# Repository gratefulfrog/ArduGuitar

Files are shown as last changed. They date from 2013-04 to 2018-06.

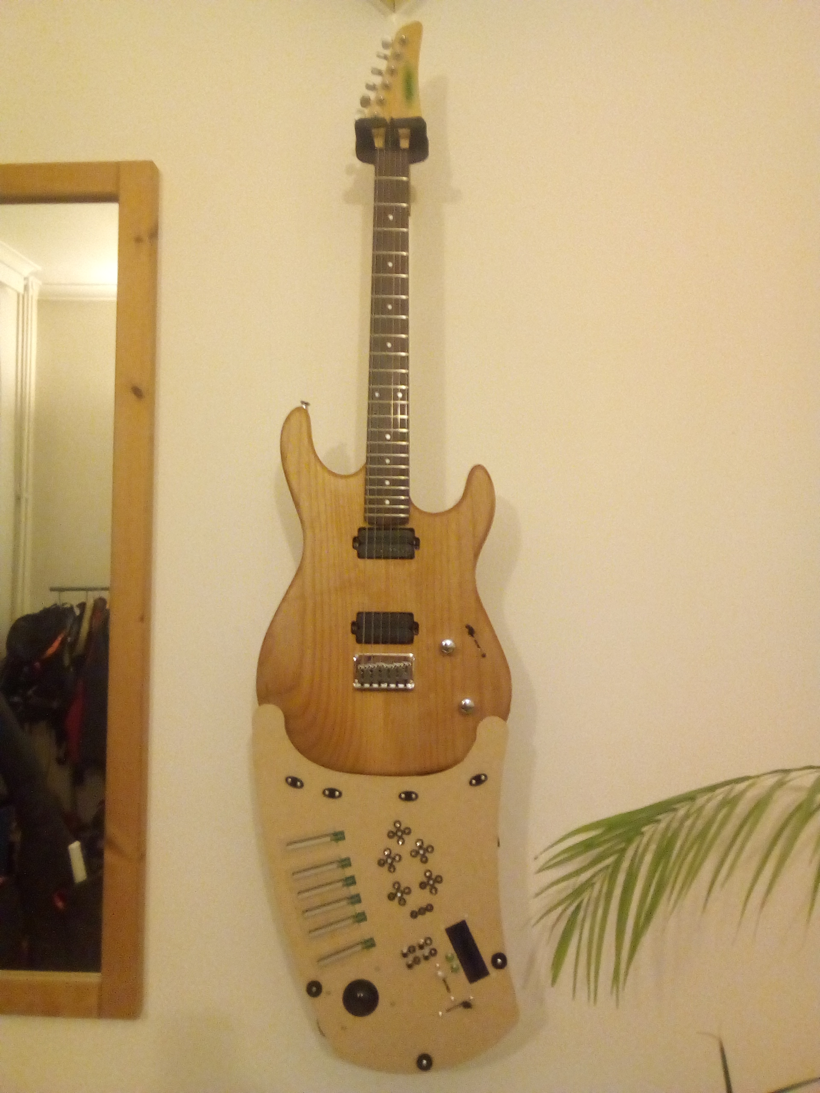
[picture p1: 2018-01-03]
Ardu2/design/POC-3_MAX395/Images/FinalAssembly/IMG_20171226_192559.jpg

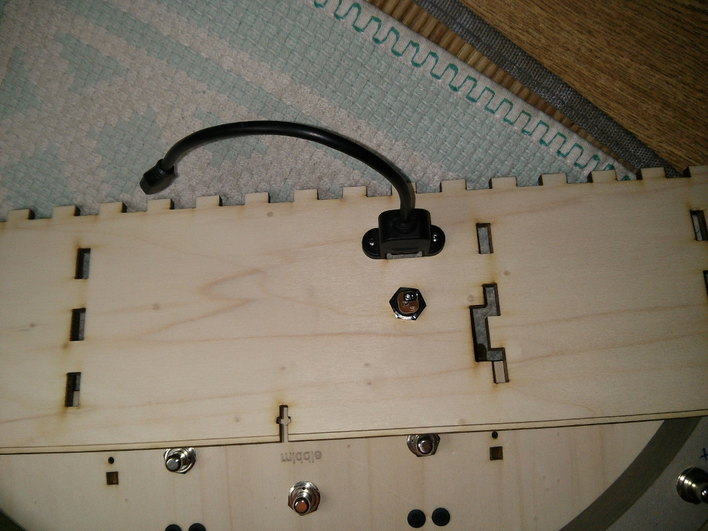
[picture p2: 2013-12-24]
arduino/Layouts/ArduStomp/EnclosureDesign/Photos/IMG_20131224_123505.jpg

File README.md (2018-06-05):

The ArduGuitar 
==========

Following Microsoft's purchase of Github, this project has migrated to gitlab.

*Electric guitars with Pyboards or Arduinos inside* 

by gratefulfrog on www.arduguitar.org

V2 is now nearly ready with a new, super evolved circuit allowing nearly limitless possiblities (2015 06).  

Although, that seemed true at the time (June 2015), it took another year to get to the first workable version of both the hardware and the software!  As of 4 September 2016, we have bench tested v0.99 of the PyGuitar software and will soon put that sw on the hardware and give it a go! 

The new circuit is  driven by a [Micropython Pyboard](http://micropython.org/).

The whole story is documented [here](https://docs.google.com/document/d/1oo2Q_3ezPv_WPeJZZisc5ifhc270i9kwir6oPctKts0/edit?usp=sharing)!

-------------

V1.1 : ArduStomp and ArduGuitar updated functionality

The ArduStomp pedal interface works well and the updated Android GUI does too!

Now ready to move on to Ardu2 !
-------------

V1.0 : a fully functional Android App with Automation capability!

The sound is near perfect, there are no known bugs! 

Now using a heavily shielded Sparkfun BlueSMIRF bluetooth board and micro_protocol_03 at 115200 baud.

-------------

V0.0 : A working Android App controlling an electric guitar!

The Processing code in the android directory works with the Arduino Micro code in the micro_protocol_02 directory to collectively form the first major milestone of the project: A fully functional android app communicating with the Ibanez RG140 circuit. 

The circuit is controled by an arduino "Micro" and communicates via a JY-MCU bluetooth module.  
        
The Processing code is based on the linux python version in the linux directory. The Ketai Processing library is used for android and bluetooth support.
        
There are too many people to thank individually for all the help and support that they gave me during this work, but the core team of Blake, Enrico, Jean and Luis really made this project possible. The Brussels Hackerspace community also provided great ideas to advance the work.

My profound thanks to them and to all the others!

Now using SSH 2016 12 24

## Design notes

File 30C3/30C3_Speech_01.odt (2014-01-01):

# Intro

{SLIDE: opening page}

2 subjects:

1. The ArduGuitar Project
2. Everything that went around the project, the meta-project.

I am not going to define all the terms and references as I speak. giyf.com can do that for you.

I am going to speak for 25 minutes and will take questions at the end. Please hold your questions for the end, or see me later.

I will not be playing the guitar on stage here - there's a limit to how much of a fool I am willing to make of myself.

But, I might make a small demo if there's enough time.

In any case, demos will be given later in the hardware hacking area.

# Who I am

I am characterized by 2 things:

1. Lots of dreams
2. very very little money.

Having very little money, and necessity being the mother of invention, lead me to learn how to get by without buying lots of stuff.

By this I mean scrounging around and fixing broken things.

I think that today there are very few broken things I could not fix, if I really wanted to. I spent all my life learning that.

Along with learning to fix things, I learned to fear breaking things that I would not be able to afford to replace...

Fear is a bad thing.

The song says, “When you've got nothing, you've go nothing to lose.” But it's more like, “when you've got nothing, you can't afford to lose anything!”

So being poor was a mixed blessing:

- it forced me to learn lots of stuff,
- but it made me scared of losing stuff, too.

But there is one other thing that characterizes me:

- Tenacity. I never give up.

This too can be a mixed blessing...

# My Vision

So back to the why I am talking to you.

In my poverty and dream to play electric guitar, over time I had found cheap broken guitars and tried to fix them.

I learned what an electric guitar was made of:

{SLIDE: an electric guitar photo of my Godin}

- pickups which capture the vibration of the string and output an audio signal (whatever that means),
- switches to route the signals from the pickups,
- Volume controls: potentiometers,
- Tone controls: potentiometers + capacitors,
- output jack: where all the signals end up and go off to the amplifier.

So there wasn't much to it.

At this point my understanding of electronics could be completely described by:

{SLIDE: V= IR}

- V = IR

That's all I “knew.” But even that I hardly understood.

This was the state of my being for around 30 years.

In the meantime, I had gotten a job and had revenue that allowed me to do more than dream.

I finally started taking guitar lessons, and got a serious guitar.

The guitar was too serious for me to wreck so I brought it to some luthiers (guitar makers) for adjustment and became friends with them.

From them, I learned that even top-end, ultra-expensive electric guitars were still made exactly as they were in the 1950s.

In fact, some guitars with 5 figure price tags were put together by people who could hardly solder...

I should tell you that for a long time I missed the 1960s.

I'm a hippie since my teenage years....

I thought that the 60s were as good as it could get, and in some ways that remains true today...

But, I love the 21st century. I love what modern technology and Internet have made possible.

I developed a vision of a 21st century electric guitar.

It should maintain the audio qualities of the 20th century guitar, ie. analogue sound from pickups.

But it should be controllable numerically, programmatically, remotely, wirelessly, etc.

Most of all, it should free the guitar of the physical constraints of electromechanical controls (space limitations, human memory, no presets...)

{SLIDE image of the guitar with buttons and the the guitar with a tablet next to it. }

I wondered why guitar electronics had not advanced. I discussed this with many pros in the music business: players, builders, engineers,...

The universal reply comprised 2 points:

{SLIDE : Why not done yet?}

- It would be incredibly difficult and expensive to do anything other than what we have today.
- No one would ever want anything other than what we have today.

Depending on the person, one or the other of those reasons would be underlined.

As the greatest mind of the 20th century said, “What do you care what anybody else thinks?” (if you want to know who said that, giyf.com).

So no one wanting my idea didn't matter. I wasn't trying to sell it anyway.

But the incredible difficulty part was another story. I knew nothing about electronics and had no idea where to begin. I also had plenty of other things to do with my time.

For a year, the project laid dormant.

# Inspiration

{SLIDE: Inspiration: TED: “the community of inspiration”}

One of the things that makes the 21st century a great time to be alive is the rise of communities. Dispersed communities, living on Internet's long tail. (If don't know what the long tail is? giyf.com)

How many people here have heard of Marshall McLuhan? Show your hands please? Can you name any of his books?

Recently, I was re-reading his seminal work “The Medium is the Massage” in the Brussels Metro. Even today, it seems so wildly subversive that I kept looking over my should to see if anyone was watching me...

Luckily, only the NSA was there - aren't they doing a Great Job !?

In 1962 Marshall McLuhan predicted the arrival of Internet:

{SLIDE: Marshall McLuhan}

"In this new age, humankind will move from individualism and fragmentation to a collective identity, the global village."

He was a profoundly forward looking thinker... He also wrote something which was directly applicable to my situation:

"When faced with a totally new situation we tend to always attach ourselves to the objects, to the flavor of the most recent past. We look at the present through a rear-view mirror. We march backwards into the future."

That means that whenever we see something that is new to us, we evaluate it relative to our past, and in particular to our recent past experiences. This can lead people to misunderstand, or to avoid innovation.

An example of this comes from what may be just a made-up conversation but it illustrates the point:

Henry Ford was asked to explain how he knew that people would want his automobiles, did he ask them about what they wanted before he made them?

He replied,

"If I had asked people what they wanted, they would have said faster horses."

Ford wasn't interested in horses.

–

All that thinking was very “a propos” to my project:

- it was too different from anything to which people could refer, so they couldn't imagine it,
- it wasn't a faster horse.

A long time had gone by since I had the idea to make a 21st century electric guitar. I had stopped actively pursuing the problem and was thinking about other things.

Then, at the end of 2012, I went to the Brussels TEDx and that made all the difference.

Mitch Altman spoke at that event and his talk was so inspiring to me that at a break I talked to him about my idea. In a minute he convinced me that it was both a good idea and very possible. He told me to try the Brussels hackerspace community for help.

So all these pros, and people I knew said forget it; I meet some guy I never heard of before who says it will work and I decide to do it.

Is Mitch Altman in the room? If he is, please stand up, Mitch.

{SLIDE: Thanks Mitch!}

Thank you for making all this possible.

# Tech Talk

That was the end of the meta-project talk.

Now, I'm now to talk about the actual implementation of the ArduGuitar and tell you about the what I actually built.

Please excuse me for any errors I may make due to my limited understanding of all this stuff.

So remember the Electric Guitar circuit? A switch, 2 pots and a capacitor.

The real problem was how to make a digitally controlled version of a mechanical analogue potentiometer.

{SLIDE: pot circuit}

Really, that's all that is needed to make a digitally friendly electric guitar. Just replace the old fashioned mechanical potentiometers with something which can add resistance to an analog voltage while being controllable from a digital device.

But, how could that be controlled digitally? I had no idea.

So I asked a question on the Belgian Hackerspace mailing list. At first, it seemed like there was some kind of communication problem.

Ever seen the film, “Cool Hand Luke”? Paul Newman's acting masterpiece?

“What we got here, is a failure to communicate.”

## LED-LDR

But, after a few iterations, and lots of patience on the part of the hackers, someone, in fact a brilliant scientist named Johannes Taelman, suggested using “LED-LDR” to make a digitally controlled variable resistance.

By the way, Johannes is currently in the hardware hacking hall showing off his own really cool project and I strongly recommend visiting him there!

I had no idea what that a LED-LDR was, but I learned that it was actually 2 things:

- a LED to shine light,
- a Light Dependent Resistor that changes its resistance depending on how much light it receives.

Although it took me several weeks to understand enough about what that was and to see how to use it, I soon realized that 2 of these LED-LDRs could be used to make a potentiometer!

{SLIDE: Pot + LED-LDR}

I had gone through Banzi's book “Getting Started with Arduino” so I sort of knew how to control the brightness of a LED …

I was in business.

And I could even use a LED-LDR as an on-off switch, so all the problems were solved!

At this point, someone on the hackerspace mailing list told me,

“It will certainly work to some extent, and even if the result is too noisy or bad quality to be used in music, it will still be huge fun to make it.”

I mention that, because it was a bit worrying. I hadn't considered “noise” at all. My simplistic V = IR understanding didn't contain any notion of noise.

I was going to pay for this later on...

By the way, LED-LDRs come as pre-assembled components. There are several types with slightly differing specs. They are called Vactrols and the best ones come from Perkin-Elmer.

## Secondary Issues

Once the key problem of making a digitally controllable analogue potentiometer was “solved”, sort-of, the rest of the issues in the project needed to be addressed. In particular the overall design.

I read the great book “Making Things Talk” by Tom Igoe and learned about serial communication and Bluetooth. It seemed straightforward.

My conceptual idea was established:

- the guitar would have an arduino embedded in it, with the Vactrols, and a Bluetooth module,
- a bluetooth device, such as an Android phone or tablet, or even a computer would have a GUI to send messages to the Arduino and control the guitar sound.

It seemed simple enough.

And it was!

{SLIDE: schematic}

This is the schematic of what's in the guitar I have here.

- Upper left: pickups, note single and double coil
- Center top: 4 switching Vactrols, LED is just full on or full off, no PWM
- Center: orange raw signal bus, heading to the volume and tone control vactrols
- Center lower: Volume and Tone control Vactrols, Note that a 3rd Vactrol is used in the volume control to shunt and get maximum volume.
- Left lower: blue output bus, with tone capacitor to ground part of the the tone low-pass filter,
- Lower left: output jack to cable to amp; Note the amp ground is the guitar ground; the Arduino & 9V ground is isolated by the opto-isolating Vactrols.
- Right: the Arduino and Bluetooth module and 9V battery.
- lower: the current limiting resistors for the Vactrol LEDs. Note: the R values for the Tone & Volume controls were determined empirically, and seem to be incoherent with the vactrol specs from the Data-sheets... I have no explanation.

Being a pretty good programmer, I got this coded & running quite quickly on a breadboard.

I got an old Ibanez RG-140 and took out all the circuitry.

I connected a very cheap JY-MCU bluetooth module to an Arduino micro which would fit in the guitar's electronics cavity with the vactrols.

I wrote a GUI in Pyside (Python+Qt) for my Linux laptop and everything was cool.

This had taken 2 months. I felt ecstatic!

When I plugged in the Guitar for the first time and it worked... I felt like Dr. Frankenstein when the lightning brought life to his creation!

It was a great moment!

Now, all I had to do was port the python gui to Android!

## Oops...

This is when I began a roller-coast ride, yo-yoing between great hope and total despair for a real really long time.

It turned out to go from Python on linux, to Java on Android was a big step!

I do not know Android, nor the java framework for Android.

I tried to make the Python work on Android, but this was very slow going...

Finally, I discovered that Processing could compile to Android-java!

Cool, I thought, progress at last.

But the GUI components and the Processing Bluetooth library (Ketai) were not easy to get to work - and there were some defects.

I also discovered some errors in Tom Igoe's book - when I wrote to him, through the publisher, he admitted to not testing all his code!!!

But in the end, I had a working Processing GUI running on Android!

{SLIDE: technology}

## More Problems

Suddenly I had a really cool thing and the same professionals who had told me to forget it a year earlier, now loved it and had “suggestions”.

The most obvious suggestion was to “Get rid of that whistling noise!”

Indeed, at each bluetooth exchange, a high frequency clicking or whistling sound came through the amp. I couldn't understand how that was possible since the audio and the control circuits were separated by light!

Another good suggestion was to make it possible to automate the changes of configuration. An example would be to make a tremolo effect by going for high to low volume every ½ second.

Also, in showing it to people and talking with them, I found terminology mismatches: for example, I had called the saved settings “configurations”, but musicians all asked if that was like “presets”.

I changed the name to presets. And made ones that people could relate to like, Eric Clapton's famous “Woman” tone.

The automation was easily done.

Getting rid of the noise was a nightmare.

I asked everyone everywhere for help.

All the forums. I had forum threads with thousands of views...

The Arduino forums were especially friendly, but at the end, no one anywhere seemed to understand what the problem was or how to fix it.

## Finally...

Then I thought to ask Bluetooth experts. After all, maybe the 5€ JY-MCU was just adding noise?

So I contacted Sparkfun support to ask about their Bluetooth modules (costing 30€). They were really nice and tried to help but told me that they used Roving Networks BT chips and advised to contact Roving support.

This was the breakthrough: RN support was great, even though I wasn't a customer! They looked at the spec for the JY-MCU and explained to me what was wrong with it and why their chips cost more: Shielding, respecting standards, more capabilities and DOCUMENTATION!

Getting a new Sparkfun Bluesmirf based on the RN42 bluetooth module got rid of almost all the noise!

Suddenly I had something GREAT!

But still not perfect.

I contacted shielding companies, got samples, learned about how to ground shielding...

## A Small Miracle

Remember I had implemented automation? Well that turned out to be fundamental in searching for the noise source. By running the coms automatically, I discovered that the gold tip of the guitar cable could act like a stethoscope. The other end was plugged into the amp turned up to full volume. I could sniff around the circuit and see where the noise was strongest.

It was not from the Arduino.

It was not from the RN42.

It was from the Serial TX and RX wires connecting the RN42 to the Arduino!

Those square waves were pulsing out EMI !

I heavily shielded the wires from the BT module to the circuit board and life was beautiful!

And I was invited to a Maker Faire...

And there was a write up on HackADay...

And I was invited to speak here today.

Now let's look at it work.

I'm sorry for the latency between the tablet and the computer, the refresh rate is only about 3 frames/sec....

{Screencast & Demo}

# Learn this stuff

Showing your work is really important. Getting feedback, both positive and negative are really helpful.

New ideas come and old problems disappear.

So if you are making stuff, even little stuff, be sure to show it around - and not just to experts.

Show it to anyone who'll take the time to look!

# But now that I had something...

I had something to lose...

I found that I had become afraid to make changes in the code, and in the circuit since I had managed to reach a delicate equilibrium state:

- It worked, but I didn't really know exactly how or why.
- So, if I tweaked something, I might break everything....

I did a lot of code review to improve things.

I am still searching for an electronics person to study the circuit and help me understand the noise and shielding issues...

# The Future: ArduStomp

Big pro-musicians have sound-board operators and stage help etc. These guys manage the effects, and could use the Android version of the ArduGuitar interface to support their guitar players, but what about people like me - remember it was for me!

A foot-pedal would be so much easier than a touch-screen.

Voilà : the ArduStomp!

{sketchup Enclosure 01.skp }

With some problems of its own!

I'll be in the Hardware Hacking Hall this afternoon if anyone wants to see the guitar and Android interface.

# Thank you all for your patience

{SLIDE: thanks}

I'll answer any questions now, or you can see me in the hardware hacking area this afternoon.

# To Show the App set this up before hand!

$ adb devices
List of devices attached
015d8bed2b17f410 device

$ javaws androidscreencast.jnlp

right click to set landscape, then resize window

Sorry for the poor refresh rate.

or (but no better)

$ java -jar droidAtScreen-1.0.2.jar

sketchup Enclosure 01.skp

2013/12/29 www.arduguitar.org @ 30C3 9/9

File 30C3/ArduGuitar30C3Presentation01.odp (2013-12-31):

## www.ArduGuitar.org

Wireless control of an Electric Guitar

## Electric Guitar

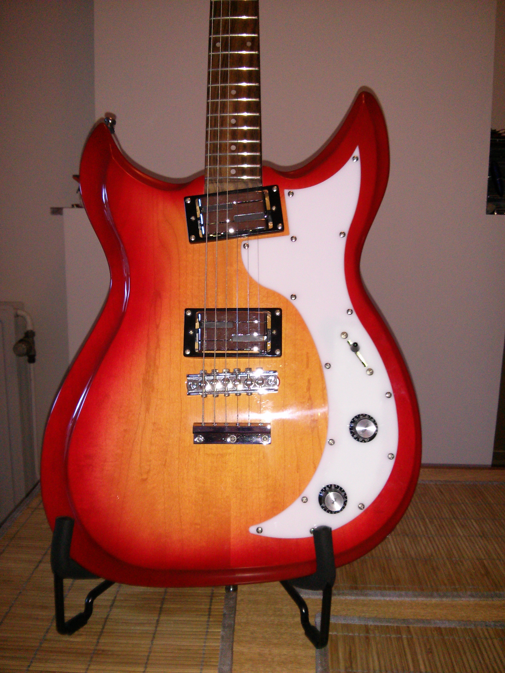
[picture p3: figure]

## All I knew...

  V = IR

## Vision

Control this

Android Phone

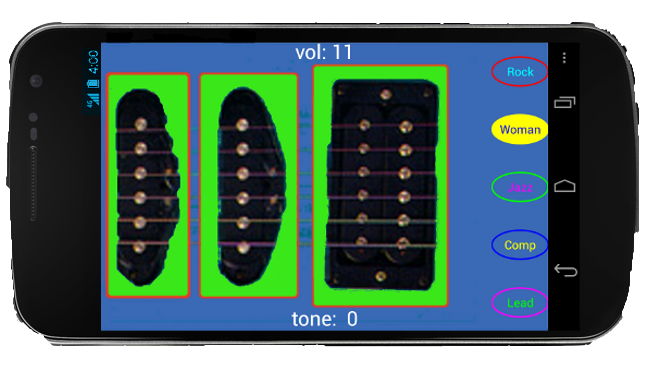
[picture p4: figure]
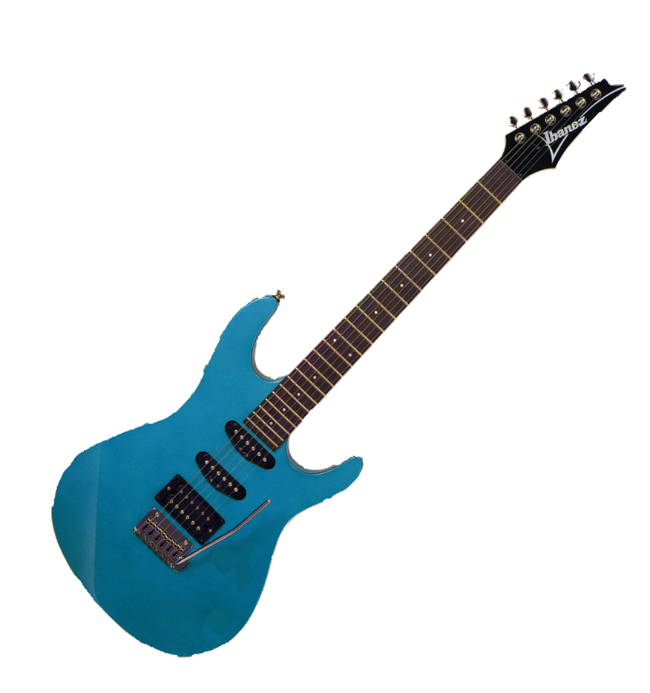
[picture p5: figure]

Play this

Electric Guitar

remote

No Knobs

or Buttons !

## But, why didn't this already exist?

  - Too difficult to build
  - Nobody wants it

## TED

  a Community of Inspiration

## Marshall McLuhan (1962)

  “In this new age, humankind will move from individualism and fragmentation to a collective identity, the global village.”
  and
  "When faced with a totally new situation we tend to always attach ourselves to the objects, to the flavor of the most recent past. We look at the present through a rear-view mirror. We march backwards into the future."

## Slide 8

  Thanks, Mitch!

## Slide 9

the Pot

Potentiometer

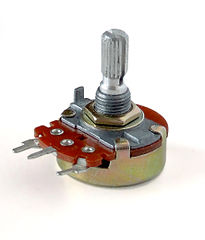
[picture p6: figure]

Manually

turn knob

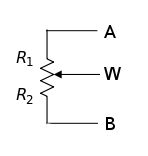
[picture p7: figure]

R1 and R2

Vary

Analog Pot

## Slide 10

the Pot

Potentiometer

Vactrols

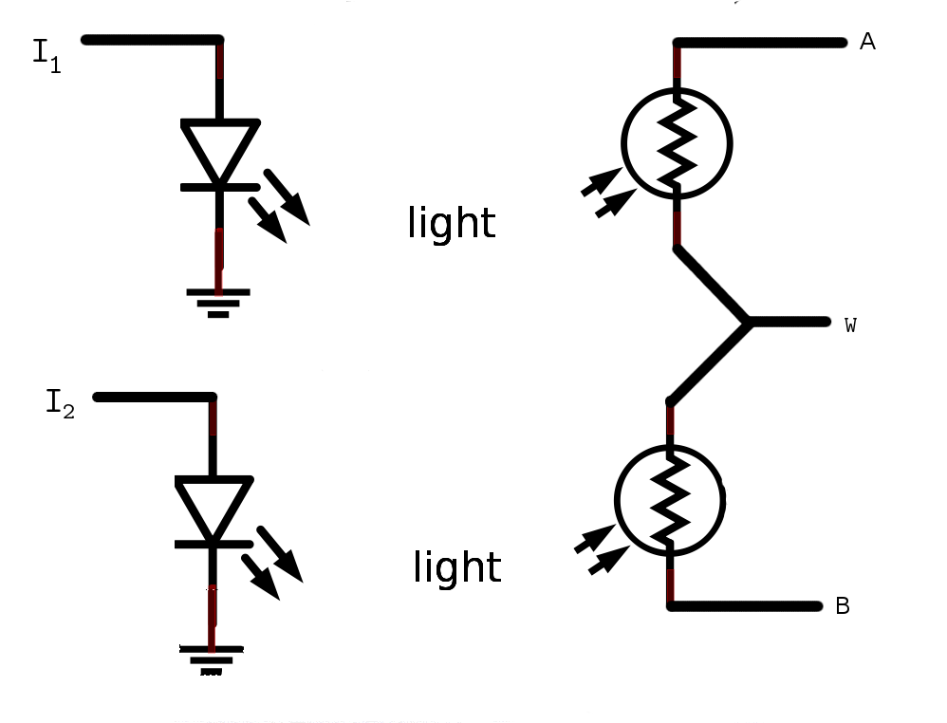
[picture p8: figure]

Manually

turn knob

R1 and R2

Vary

R1

R2

Electronically apply current

R1 and R2

Vary

Digital control - Analog Pot

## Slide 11

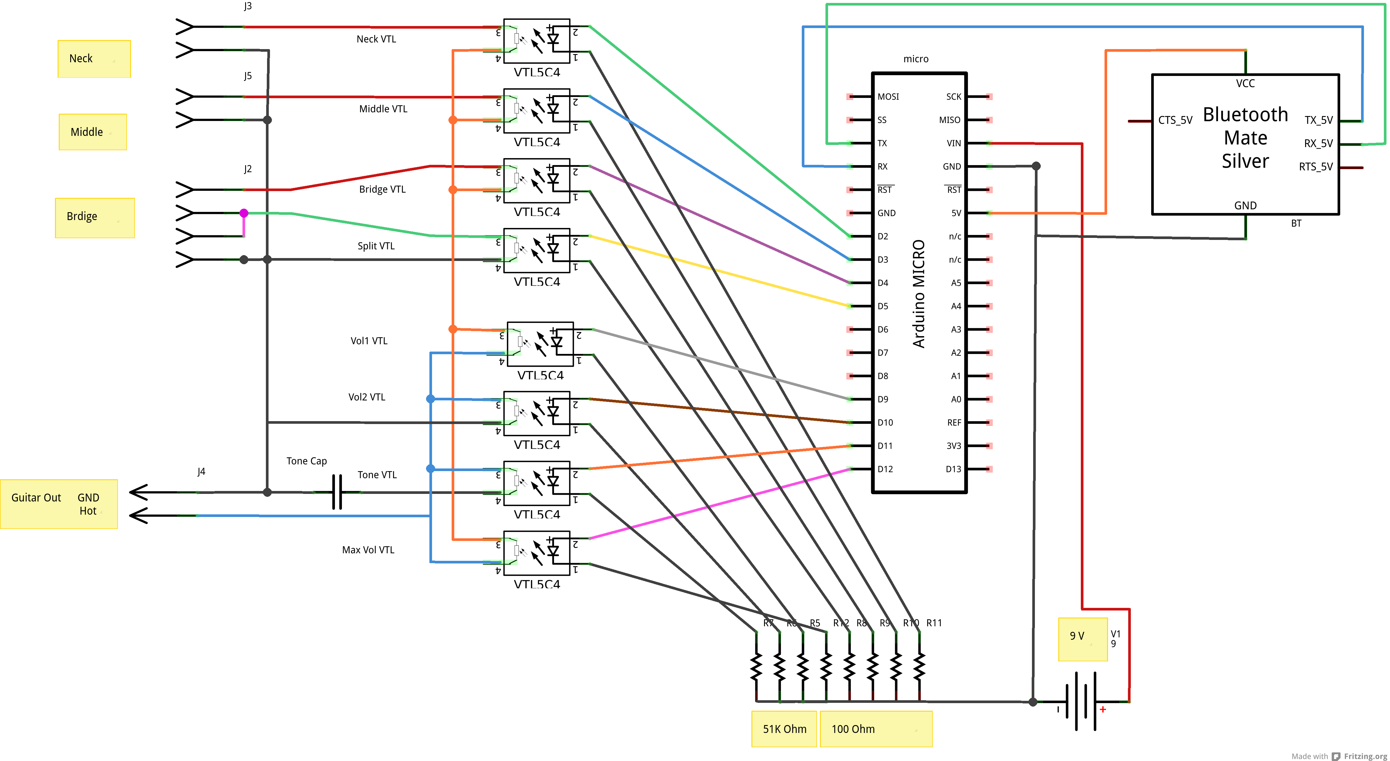
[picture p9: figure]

## ArduGuitar Technology

Vactrols

Arduino Micro C++

Bluetooth

Processing

Android

Bluetooth

wireless

## Thanks!

  www.arduguitar.org

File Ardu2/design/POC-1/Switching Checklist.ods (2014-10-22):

 | OUT+ | OUT- | A+ | A- | B+ | B- | C+ | C- | D+ | D-
A+ | Y | X | X | X | Y | Y | Y | Y | Y | Y
A- | X | Y | X | X | Y | Y | Y | Y | Y | Y
B+ | Y | X | X | X | X | X | Y | Y | Y | Y
B- | X | Y | X | X | X | X | Y | Y | Y | Y
C+ | Y | X | X | X | X | X | X | X | Y | Y
C- | X | Y | X | X | X | X | X | X | Y | Y
D+ | Y | X | X | X | X | X | X | X | X | X
D- | X | Y | X | X | X | X | X | X | X | X
 | OUT+ | OUT- | A+ | A- | B+ | B- | C+ | C- | D+ | D-
A+ | 2D | X | X | X | 2B | 1A | 1B | 1D | 1C | 2A
A- | X | 5D | X | X | 4D | 5A | 4A | 4C | 4B | 5B
B+ | 2C | X | X | X | X | X | 3B | 3D | 3C | 3A
B- | X | 5C | X | X | X | X | 6A | 6D | 6C | 6B
C+ | 7D | X | X | X | X | X | X | X | 7A | 7B
C- | X | 8D | X | X | X | X | X | X | 8A | 8B
D+ | 7C | X | X | X | X | X | X | X | X | X
D- | X | BC | X | X | X | X | X | X | X | X

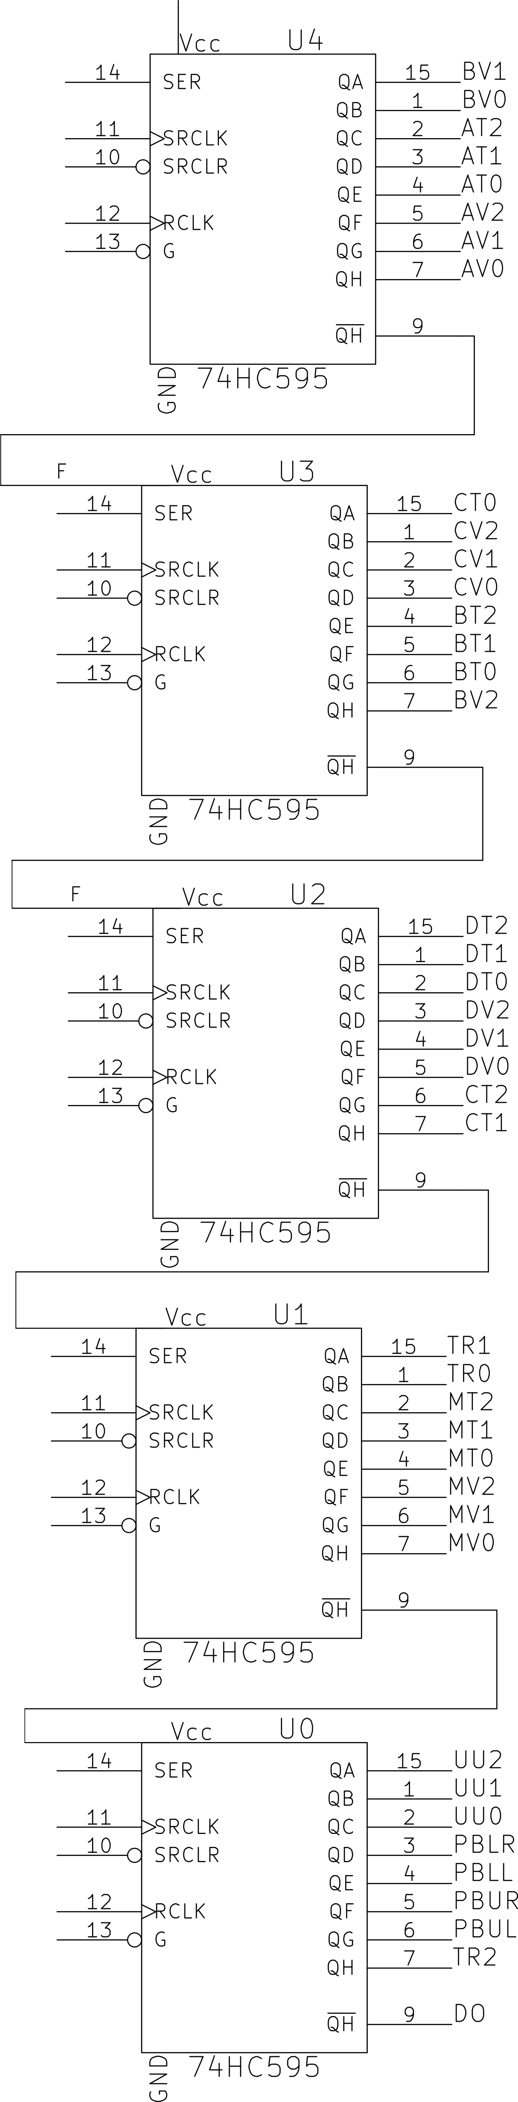
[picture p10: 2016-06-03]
Ardu2/design/POC-3_MAX395/HMI/KicadProjects/Main HMI Circuit/Images/HMI LED PCB Schema.png

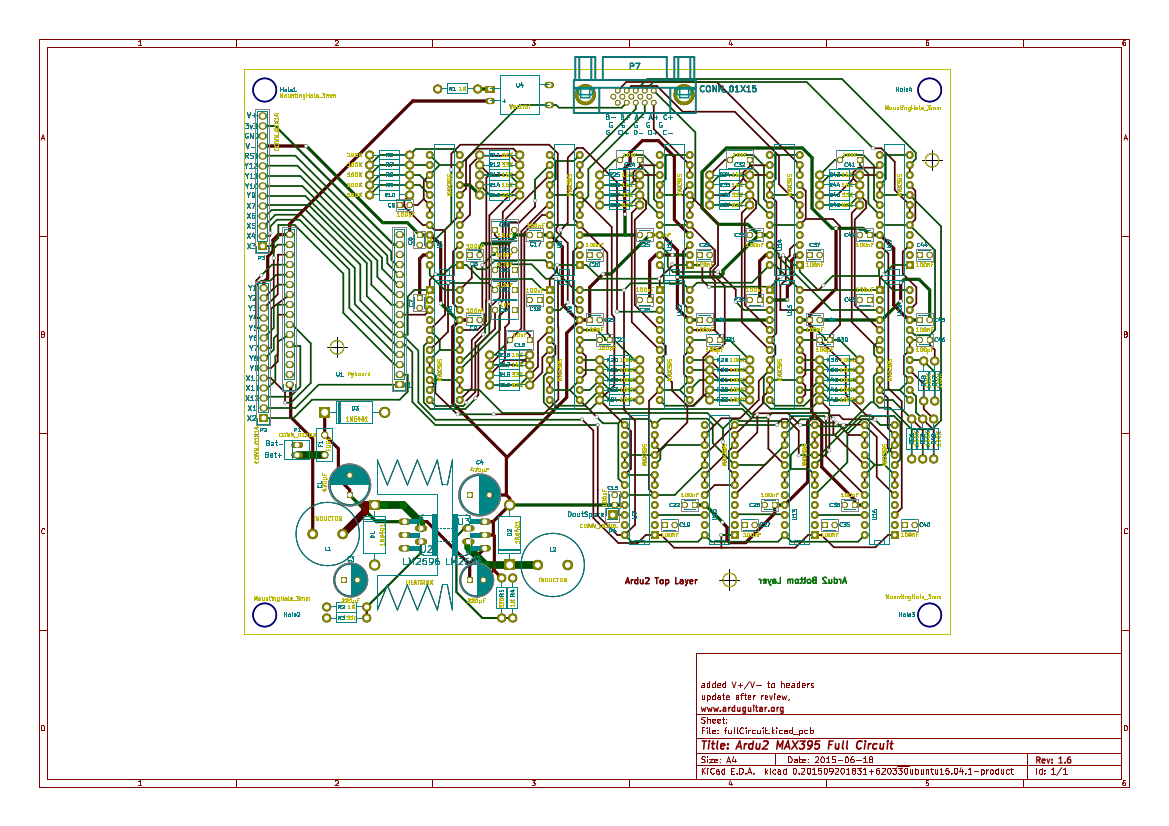
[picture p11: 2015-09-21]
Ardu2/design/POC-3_MAX395/KicadProjects/FullCircuit/Images/V1.8/FullPCBUnfilled.png

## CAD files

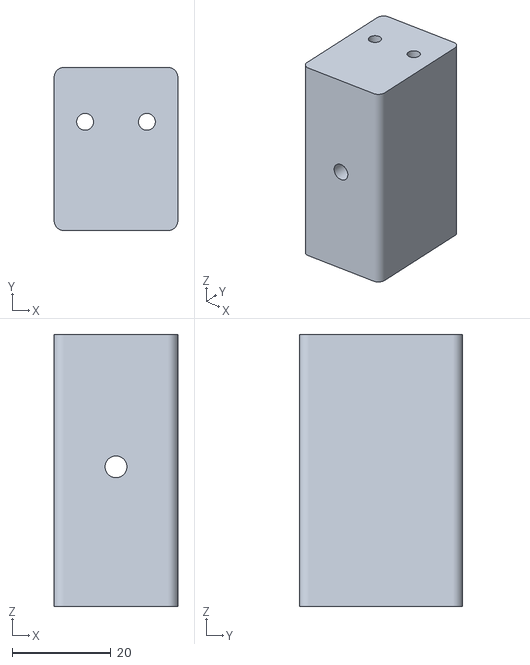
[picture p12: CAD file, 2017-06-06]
Ardu2/design/POC-3_MAX395/HMI/MountingBlocks/lowHoledMountingBlock.stl
25.0 x 33.0 x 55.0

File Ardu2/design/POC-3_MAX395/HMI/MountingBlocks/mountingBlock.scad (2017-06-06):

$fn=100;

// nut dimensions wrench, height, epsilon
/*  UNUSED
wNut = 5.5;
hNut = 2.5;
eNut = 0.2;
*/

// guitar max thickness at butt
hGuitar = 44;

// block height,width,depth
hBlock = 55;
wBlock = 25;
dBlock = 33;


// slot height above base and below top of column, all the rest is computed
sHeight=10;

// dBolt depthwise offset from face away from guitar
dOffset = dBlock/3.;

//hBolt hole offset from base
hOffset = hBlock-hGuitar/2.0; // high hole centered
hlOffset =  28.25;  // low hole average of 28 and 28.5

// bolt diamenters and epsilon
dBolt = 3;
hBolt = 4;
eBolt = 0.2;

// oval cover plate, ratio of ovality 2/1
hPlate = 3;
wPlate = wBlock;
ePlate=1;
ratioPlate = 0.5;

// single hole cylindrical spacer
dCy = 20.0;
hCy = hBlock;

// drilling jig
// 
hPanel = 3.0;
jigEpsilon = 0.2;
wJigCol = 5;
wJigHole = 5 + jigEpsilon;
hJig =  hPlate;
hJigCol = 2*hJig+ hPanel;
wJig = wBlock;
dJig = 50;
dColBack = 23;

module jigCol(wid,h){
    cube([wid,wid,hJigCol], center=true);
}
module jigCols(doCol){
    colY = -dJig+dColBack;
    color("SteelBlue")
    if(doCol){
        translate([-wJig/6,colY,hJigCol/2.])
            jigCol(wJigCol,hJigCol);
    }
    else{
        #translate([wJig/6,colY,0])
            jigCol(wJigHole,hJigCol);
    }
}
module jigPlate(){
    db = dBlock;
    do = dOffset;
    bDia = dBolt;
    bEps = eBolt;
    difference(){  
        union(){
            block(hJig,wJig,dBlock);
            translate([0,(dBlock-dJig)/2.,0])
              block(hJig,wJig,dJig);
        }
        // holes for vertical bolts
        #translate([wBlock/4.0,db/2.0-do,-10])
            column(bEps+bDia/2.0,hBlock+20);
        #translate([-wBlock/4.0,db/2.0-do,-10])
            column(bEps+bDia/2.0,hBlock+20);
    }
}

module jigAll(){
    difference(){
        color("SteelBlue")
        union(){
            jigPlate();
            jigCols(true);
        }
        jigCols(false);
    }
}
                
module cyPlate(){
    color("green")
    //scale([1,1,1])
        cylinder(d=dCy-ePlate,h=hPlate,center=true);
}

module cyBlock(hh,dd){
   color("SteelBlue")
       translate([0,0,hh/2.0])
           cylinder(d=dd, h=hh, center=true);
} 

module plate(){
    color("green")
    scale([1,ratioPlate,1])
        cylinder(d=wPlate-ePlate,h=hPlate,center=true);
}
/* UNUSED
module nut(wrench,thickness){
    // make a nut, centered at 0,0,0
    r = wrench/(2.0*cos(30));
    translate([0,0,-thickness/2.0])
        rotate([0,0,30])
        linear_extrude(height=thickness)
            circle(r,$fn=6);   
}
module slot(w,l,h){
    // make a slot centered at 0,0,0
    translate([0,0,h/2.0])
        cube([w,l,h],center=true);
}
*/
module column(rCol,hCol){
    // make the column, based at 0,0,0
    cylinder(r=rCol,h=hCol);
} 
    
module block(hh,w,d,rr=2,rounded=true){
    // make a block centered at 0,0,0
    color("SteelBlue")
    if (!rounded){
        translate([0,0,hh/2.0]){
            cube([w,d,hh], center=true);
        }
    }
    else{
        x = w/2.-rr;
        y = d/2.-rr;
        hull(){
            translate([-x,-y,0])
                cylinder(r=rr,h=hh);
            translate([-x,y,0])
                cylinder(r=rr,h=hh);
            translate([x,-y,0])
                cylinder(r=rr,h=hh);
            translate([x,y,0])
                cylinder(r=rr,h=hh);
        }
    }
}
        
module all(cHeight,bDia,bEps,low, blocks,plates){
    // make a column of h=cHeight, 
    // with a bolt diamter of bDia, applying bEps
    
    hh =  (low ? hlOffset : hOffset);
    db = dBlock;
    do = dOffset;
    difference(){  
        union(){
            if (blocks)
                block(hBlock,wBlock,db);
            if (plates>0){
                translate([0,db/2.0-do,-5])
                    plate();
            }
            if (plates>1){
                translate([0,db/2.0-do,hBlock+5])
                    plate();
            }
        }
        
        // holes for vertical bolts
        #translate([wBlock/4.0,db/2.0-do,-10])
            column(bEps+bDia/2.0,hBlock+20);
        #translate([-wBlock/4.0,db/2.0-do,-10])
            column(bEps+bDia/2.0,hBlock+20);
        // hole for horizontal bolt
        if (blocks){
            #translate([0,0,hh])
                rotate([90,0,0])
                    translate([0,0,-db/2.-1])
                        column(eBolt+hBolt/2.0,db+2,center=true);
        }
    }
}


module triPlate(hh=3.0,rr=2){
    // make a block centered at 0,0,0
    //color("SteelBlue")
    x = 33/2.0-rr;
    y = 34.0-rr;
    bDia = dBolt;
    bEps = eBolt;
    difference(){
        hull(){
            translate([-x,-y,0])
                cylinder(r=rr,h=hh);
            translate([x,-y,0])
                cylinder(r=rr,h=hh);
            translate([0,0,0])
                cylinder(r=10,h=hh);
        }
        // hole for vertical bolt
        #translate([0,0,-10])
            column(bEps+bDia/2.0,hh+20);
    }
}
module triAll(){
    difference(){
        color("SteelBlue")
        union(){
            triPlate();
            jigCols(true);
        }
        jigCols(false);
    }
}
module cyAll(cHeight,bDia,bEps, cols, plates){
    // make a cylindrical column of h=cHeight, 
    // with a bolt diamter of bDia, applying bEps   
    difference(){        
        union(){
            if (cols){
                cyBlock(cHeight,dCy);
            }
            if (plates>0){
                translate([0,0,-5])
                    cyPlate();
            }
            if (plates>1){
                translate([0,0,cHeight+5])
                    cyPlate();
            }
        }
        // hole for vertical bolt
        #translate([0,0,-10])
            column(bEps+bDia/2.0,cHeight+20);
    }
}

module showThemAll(){
    translate([-wBlock-5,0,0]){   
        all(hBlock,dBolt,eBolt,true,1,2);
        translate([wBlock+5,0,0]){
            all(hBlock,dBolt,eBolt,false,1,2);
            translate([wBlock+5,0,0]){
                cyAll(hCy,dBolt,eBolt,1,2);
            }
        }
    }
}

//showThemAll();
//
module blockAll(low,blocks,plates){
   all(hBlock,dBolt,eBolt,low, blocks, plates);
}


//cyAll(hJig,dBolt,eBolt,1,0);
//blockAll(true,1,0);
//showThemAll();    
//echo("low hole vertical offset", hlOffset);
//echo("high hole vertical offset", hBlock - hOffset);

//jigCols();
//jigPlate();
//jigAll();
triAll();

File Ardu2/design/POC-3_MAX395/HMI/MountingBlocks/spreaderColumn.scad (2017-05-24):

$fn=500;

// nut dimensions wrench, heihht, epsilon
wNut = 5.5;
hNut = 2.5;
eNut=0.2;

// column height, all the rest is computed
hCol =44;

// slot height above base and below top of column, all the rest is computed
sHeight=10;

// bolt diamenter and epsilon
dBolt=3;
eBolt=0.2;

module nut(wrench,thickness){
    // make a nut, centered at 0,0,0
    r = wrench/(2.0*cos(30));
    translate([0,0,-thickness/2.0])
        rotate([0,0,30])
        linear_extrude(height=thickness)
            circle(r,$fn=6);   
}
module slot(w,l,h){
    // make a slot centered at 0,0,0
    translate([0,0,h/2.0])
        cube([w,l,h],center=true);
}

module column(rCol,hCol){
    // make the column, based at 0,0,0
    cylinder(r=rCol,h=hCol);
}

module all(wrench,nHeight,sHeight,cHeight,bDia,nEps,bEps){
    // make a column of h=cHeight, r compute from nut wrench size,
    // with a slot+nut cutaway at sHeight above base, applying nEps
    // with a slot+nut cutaway at sHeight below the top of the column, applying nEps 
    // with a bolt diamter of bDia, applying bEps
    
    wNut=wrench+nEps;
    rNut= wNut/(2.0*cos(30));
    hNut= nHeight/2.0;
    rCyl = 2*rNut;
    difference(){
        column(rCyl,cHeight);
        #translate([0,0,sHeight]){
            nut(wrench,hNut);
            slot(wNut,4*wNut,nHeight+nEps);
        }
        #translate([0,0,cHeight-sHeight]){
            rotate([180,0,0]){
                nut(wrench,hNut);
                slot(wNut,4*wNut,nHeight+nEps);
            }
        }
        #translate([0,0,-1])
            column(bEps+bDia/2.0,cHeight+2);
    }
}


all(wNut,hNut,sHeight,hCol,dBolt,eNut,eBolt);

  

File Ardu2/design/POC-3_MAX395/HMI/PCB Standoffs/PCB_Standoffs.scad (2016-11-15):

// PCB_Standoffs 
// For HMI PCB mounting to back plane

$fn = 100;
lowHeight = 5.0;
highHeight = 9.5;
m3Dia =  3.3;
extDia = 10.0;
rInt = m3Dia/2.0;
rExt = extDia/2.0;
epsilon=1;

module extCyl(height){
    cylinder(r=rExt,h=height, center=false);
}
module intCyl(height){
    translate([0,0,-epsilon/2.0])
        cylinder(r=rInt,h=height+epsilon, center=false);
}
module standoff(hi=false){
    h = hi ? highHeight : lowHeight;
    difference(){
        extCyl(h);
        intCyl(h);
    }
}
standoff(hi=true);

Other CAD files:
arduino/Layouts/ArduStomp/EnclosureDesign/2D/FullDesign08testKerfing.dwg
arduino/Layouts/ArduStomp/EnclosureDesign/2D/FullDesign09/FullDesign09.dwg
arduino/Layouts/ArduStomp/EnclosureDesign/2D/FullDesign10/DWG_2007/FullDesign10_6mm_to_cut12_2007.dwg
arduino/Layouts/ArduStomp/EnclosureDesign/2D/FullDesign10/FullDesign10_3mm_test_Laid_out.dwg
arduino/Layouts/ArduStomp/EnclosureDesign/2D/FullDesign07.dwg
arduino/Layouts/ArduStomp/EnclosureDesign/2D/FullDesign10/DWG_2007/FullDesign10_3mm_to_cut_2007.dwg
arduino/Layouts/ArduStomp/EnclosureDesign/2D/FullDesign08.dwg
arduino/Layouts/ArduStomp/EnclosureDesign/2D/FullDesign10/DWG_2007/FullDesign10_6mm_to_cut_2007.dwg
arduino/Layouts/ArduStomp/EnclosureDesign/2D/FullDesign10/FullDesign10_3mm_text_all_arcs_mirror_14_Laid_out.dwg
arduino/Layouts/ArduStomp/EnclosureDesign/2D/FullDesign06.dwg
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

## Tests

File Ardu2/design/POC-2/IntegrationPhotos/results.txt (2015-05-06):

using 1% pwm at 50000 hz, & 50ohm series resistor, I get 3.5k ohm resistance
over the photo-resistor

using the open_drain, set to high, and 1k resistor, I get 7.7 K ohm resistance 
over the photoresistor, both work well for popless shunting!

g = pyb.Pin('X1',pyb.Pin.OUT_OD)
g.low()
g.high()

c =pwmControl()
shunt(c)
shunt(c,False)

while True:
  pyb.delay(50
  doShunt()
  pyb.delay(50)
  doShunt(False)

Hi,

Here are the results of testing your suggestions :
[quote]
1- If you are able to get good 'popless' shunting at 1% PWM, that tells me that you don't need to drive your Vactrol LED at anything close to the 40-50mA that you will get at 100% duty cycle. You can probably dispense with the BJT and drive the Vactrol directly with the pyboard GPIO pin and the 3.3V supply. IIRC, the GPIO pins can drive or sink up to 20mA. Put your drive pin in open collector mode and use a 200 Ohm resistor in series with the LED to limit the current to about 10mA.[/quote]

I tried this exactly as you said, and it shunts, but the pop is back. I have tried to tune the series resistor, but I am giving up for now and going back to the PWM solution so I can continue testing other parts of the circuit.  I think this will work but the series resistor must be tuned to an appropriate value.  Ideally, it seems that the Vactrol resistance should be 3-5 k ohm to get good quiet shunting.

[quote]2- The Vactrol does not require a common ground between the LED drive circuitry and the audio circuit- you may get better audio performance if you separate them.[/quote]

Definitely not. Without the common ground, the circuit is drowned in noise.

By the way, I actually read some books and understood the idea of shunting and then empirically came to the resistor and PWM values. 

Today, in the lab, we have measured the signal on a scope and saw that on un-shunting the circuit there is a 360 micro-second long spike while the stored  energy in the audio source (an inductive source) attenuates and pure audio is then carried.  So, the vactrol ramp up time is slow enough to allow the energy to dissipate before getting to the amp. (that's what we think, anyway.)

So, the problem is sort of solved and life is as Good as it Gets!

---- The Pop ---

--- The un-shunting Pop ---

With the coil grounded, the current flows to ground at zero volts.

When the coil is un-grounded, the coil tries to conitnue the current flow through the high impedence amp by increasing the voltage. This 360 micro-second long voltage spike is what we hear as a pop.

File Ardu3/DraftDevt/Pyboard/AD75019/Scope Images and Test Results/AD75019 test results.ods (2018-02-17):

 | V to DGND
Pin | 7.6v Analog Supply | 11.3v Analog Supply
5 | <1mv | -1mv to 18mv
6 | <1mv | <1mv
39 | <1mv | <1mv
40 | 4.7v | 4.7v
Resistance between pins
4 Vss | 40 | 4M
41 Vdd | 40 | 7M
42 Vcc | 40 | 100K | Vcc to Pin 40 is far less than the others! and that is where 5v is arriving at the chip!
43 DGND | 40 | 7M
Supply current
Vcc into chip | 0mA
Vdd into chip | 0mA
Chip into Vss | 0mA

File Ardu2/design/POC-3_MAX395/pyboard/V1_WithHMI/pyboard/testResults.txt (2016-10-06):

push: 17152
pop:0x4300
Work:   K:      0b1000011       V:      0x0
PB:     3
Initialized!
Initialized!
Initialized!
Vibrato:        True
setting: None
send reg:       0       10000000
send reg:       1       10110110
send reg:       2       01100001
send reg:       3       00000000
send reg:       4       10000110
send reg:       5       00010000
send reg:       6       10010000
send reg:       7       00010000
send reg:       8       00000000
send reg:       9       10000000
send reg:       10      00001001
send reg:       11      10001001
send reg:       12      00001001
send reg:       13      10000000
send reg:       14      00001001
send reg:       15      10000110
send reg:       16      00001001
send reg:       17      10000010
send reg:       18      00000001
UNshunting
Vibrato Level:  
1
push: 2053
pop:0x805
Work:   K:      0b1000  V:      0x5
push: 17152
pop:0x4300
Work:   K:      0b1000011       V:      0x0
PB:     3
Vibrato:        False
setting: None
Shunting
send reg:       0       10000000
send reg:       1       10110110
send reg:       2       01100001
send reg:       3       00000000
send reg:       4       10000110
send reg:       5       00010000
send reg:       6       10010000
send reg:       7       00010000
send reg:       8       00000000
send reg:       9       10000000
send reg:       10      00001001
send reg:       11      10001001
send reg:       12      00001001
send reg:       13      10000000
send reg:       14      00001001
send reg:       15      10000110
send reg:       16      00001001
send reg:       17      10000010
send reg:       18      00000001
UNshunting
send reg:       18      00000001
UNshunting
push: 4353
pop:0x1101
Work:   K:      0b10001 V:      0x1
push: 4609
pop:0x1201
Work:   K:      0b10010 V:      0x1
push: 4609
pop:0x1201
Work:   K:      0b10010 V:      0x1
push: 4867
pop:0x1303
Work:   K:      0b10011 V:      0x3
VOL:    C       3
((14, 5), (3, 2), (3, 3))
((14, 3), (3, 241))
Reg:    14
Reg:    3
masking: 
['14', '00000011']
masking: 
['3', '11110001']
setting: ((14, 5), (3, 2), (3, 3))
setting: None
Shunting
send reg:       0       10000000
send reg:       1       10110110
send reg:       2       01100001
send reg:       3       00001100
send reg:       4       10000110
send reg:       5       00010000
send reg:       6       10010000
send reg:       7       00010000
send reg:       8       00000000
send reg:       9       10000000
send reg:       10      00001001
send reg:       11      10001001
send reg:       12      00001001
send reg:       13      10000000
send reg:       14      00100001
send reg:       15      10000110
send reg:       16      00001001
send reg:       17      10000010
send reg:       18      00000001
UNshunting

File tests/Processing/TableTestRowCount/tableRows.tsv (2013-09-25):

name | vol | tone | neck | middle | bNorth | bBoth
Rock | 0 | 0 | 0 | 0 | 0 | 0
Woman | 0 | 0 | 0 | 0 | 0 | 0
Jazz | 0 | 0 | 0 | 0 | 0 | 0
Comp | 0 | 0 | 0 | 0 | 0 | 0
Lead | 0 | 0 | 0 | 0 | 0 | 0

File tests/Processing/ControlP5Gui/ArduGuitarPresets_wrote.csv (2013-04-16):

n | v | t | s | l
jazz | 5 | 3 | 0 | 0
rock | 5 | 5 | 4 | 0
mellow | 3 | 3 | 5 | 1

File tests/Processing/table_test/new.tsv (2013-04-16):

x | y | z
1 | 2 | true
3 | 4 | false
123 | 456 | true
123 | 456 | false
123 | 456 | false
123 | 456 | false
123 | 456 | false

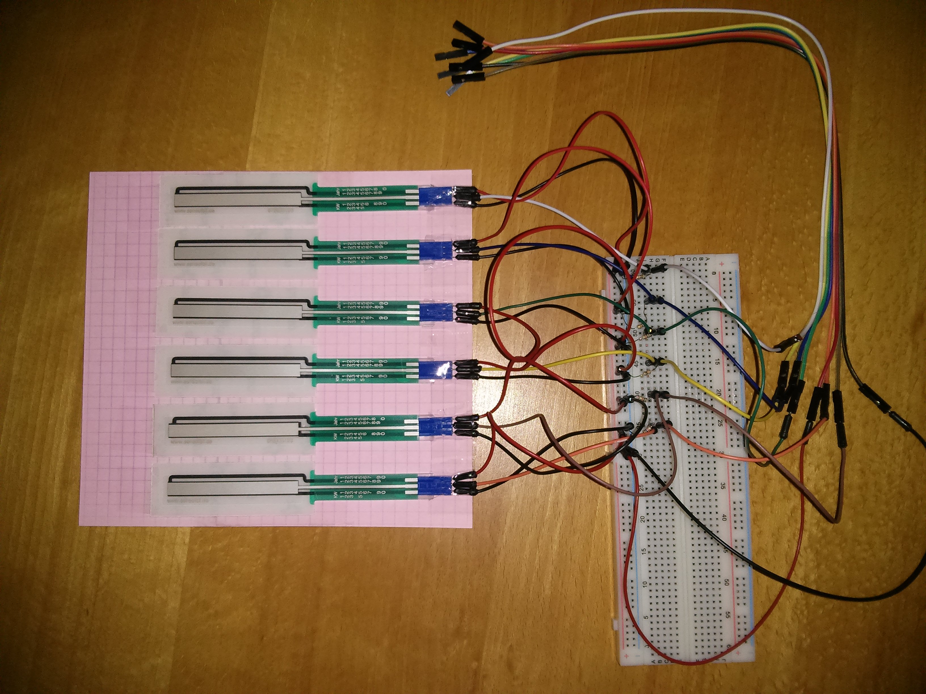
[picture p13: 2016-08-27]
Ardu2/design/POC-3_MAX395/pyboard/images/SplitPot Testbed 2016 08 27.jpg

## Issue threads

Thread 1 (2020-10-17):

Need help for noise from arduino.

kraftZeug, 2020-10-17:
Hey there.
I'm working on electric guitars with onboard midi controlers and i'm amazed at your work.
I wanted to get in touch with you for a practical question: how did you managed the noise from arduino ?

gratefulfrog, 2020-10-17:
Hi KraftZeug,

I should first tell you that all my work has moved to gitlab, so please
look there for code etc.

I had noise on my first circuit, only. I believe that this was due to
several things:

   - lack of a proper PCB: This is in my opinion the main problem. At the
   time, I did not know much and used a proto-board for the components. This
   was a big source of noise. Later, I designed a proper PCB with ground plane
   and fill and the problem was mostly solved.
   - use of unshielded wires for digital data. Another source, but much
   less than the PCB. Use very short shielded wires, soldered !
   - over use of connectors for digital data. Solder your digital cables
   wherever possible.

With these problems fixed, my 2nd circuit and my future 3rd circuit are
noiseless.

Hope this helps!
Cheers,
Bob

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

kraftZeug, 2020-10-17:
Thanks, you helped a lot.
My arduino is wired with dupont connectors and the data wires are not shielded, although guitar wires are. I'll check this..
About the code, I used tttapa's code, Control-Surface.
My next project will be an arduino based analog switching with Red Special (Brian May's guitar) like abilities.
If you're interested, you can find me on facebook and instagram..
Great work anyway, I'll follow to see your next project.

gratefulfrog, 2020-10-17:
No problem, I'm happy to help.

I cannot stress enough the importance of making a proper PCB with proper
ground plane and ground fill. This is really the biggest source of noise.

Good luck with your project!

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

Closed 2020-10-17.

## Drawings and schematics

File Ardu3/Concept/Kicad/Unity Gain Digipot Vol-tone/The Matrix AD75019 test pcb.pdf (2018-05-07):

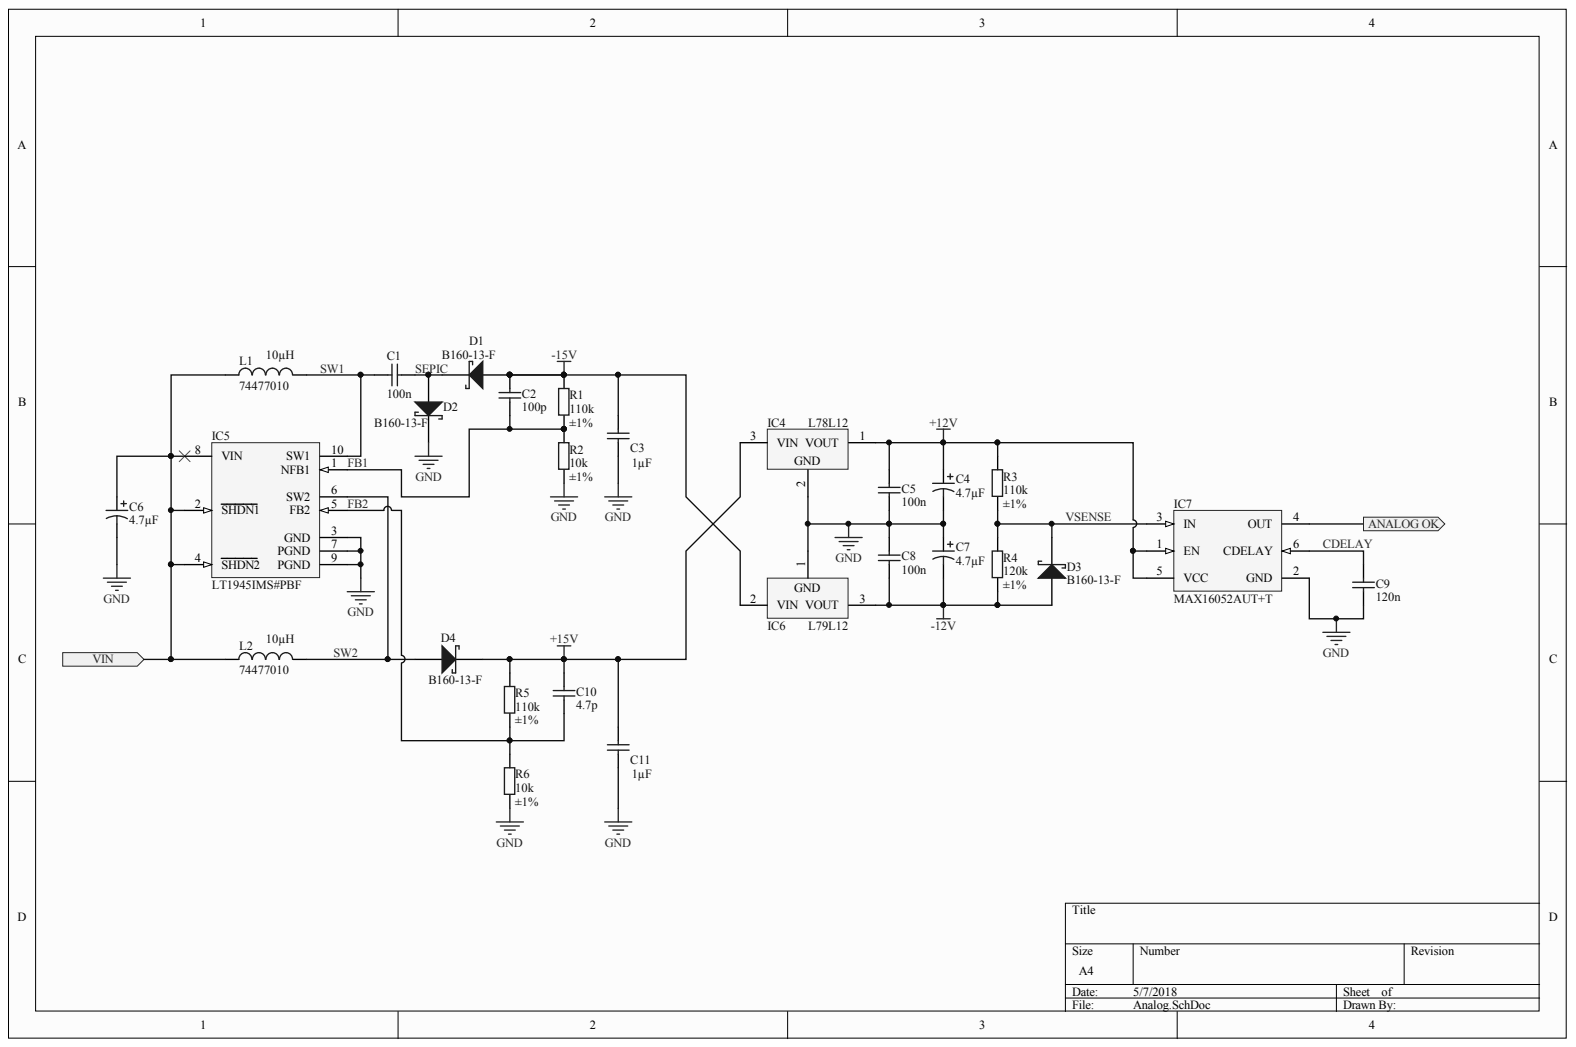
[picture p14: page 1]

1 | 6 C DELA

Numbe r | R evision

: 5/7/2018 | She et of
File : Analog. S chDoc | D r awn By:

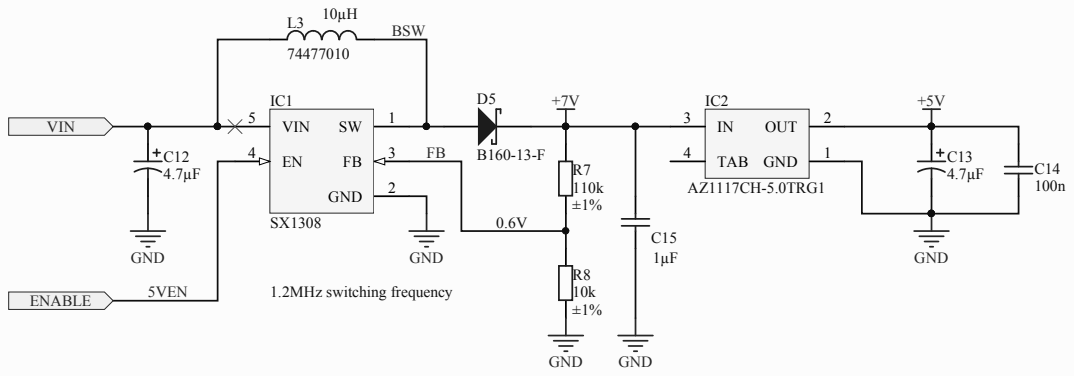
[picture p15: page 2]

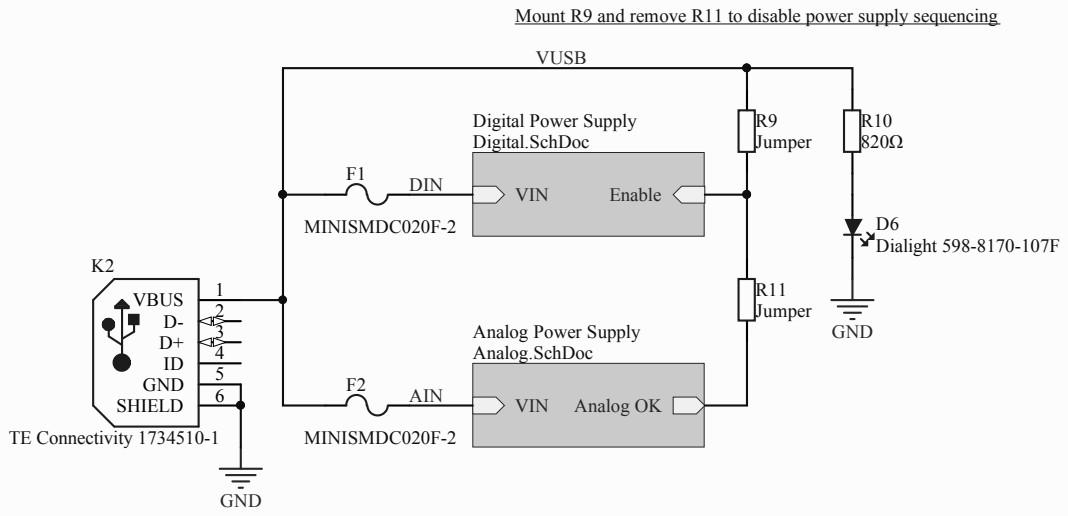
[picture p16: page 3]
R11 Jumpe; R9 Jumpe; E Conne; ight 598-8170-107F; AIN DIN; Mount R9; and re move R11; e pow

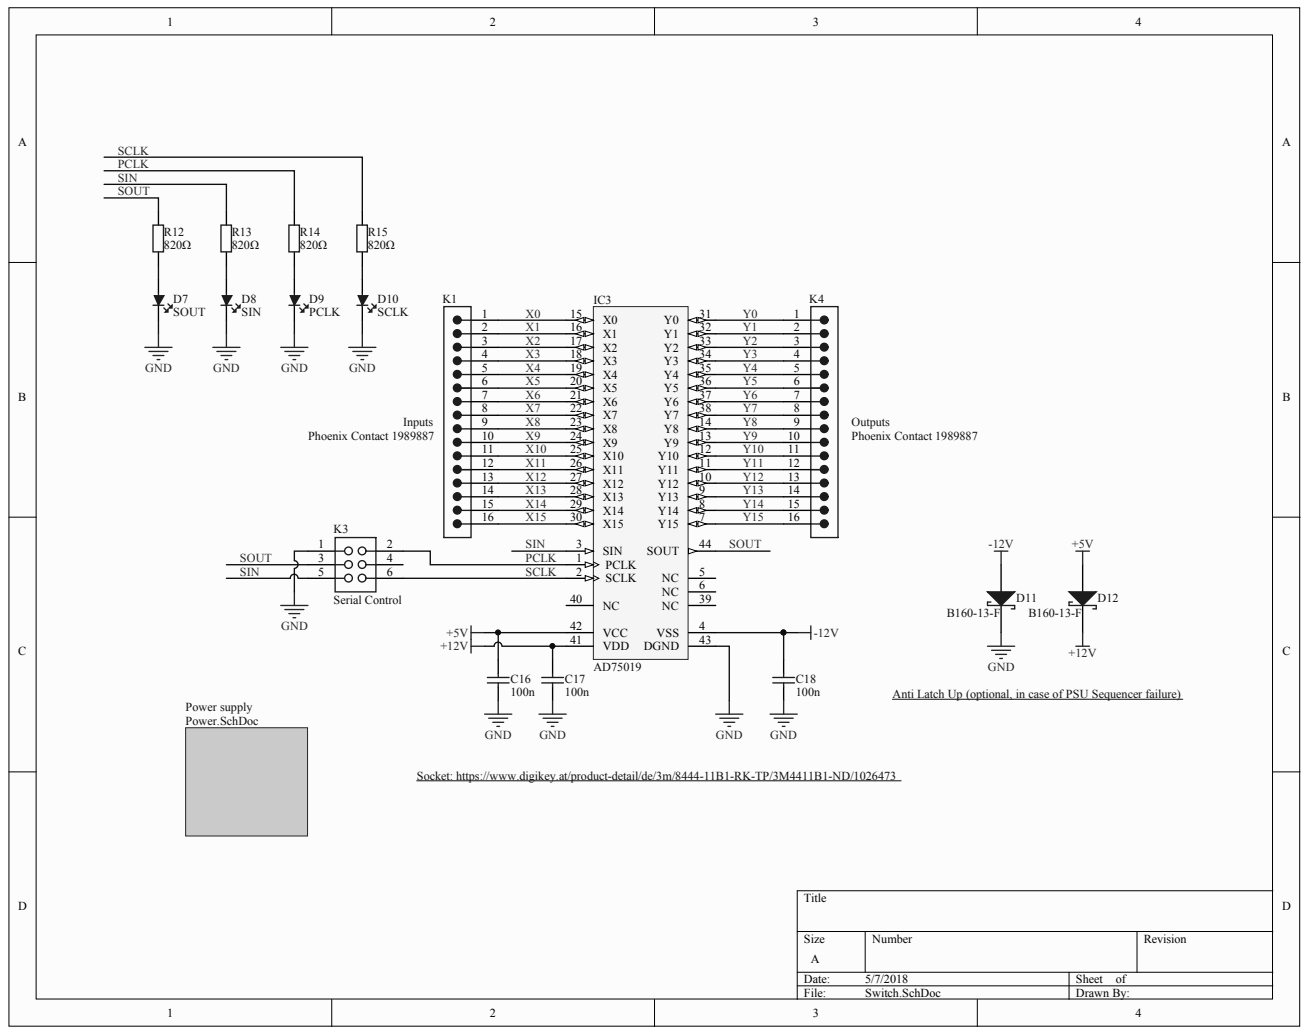
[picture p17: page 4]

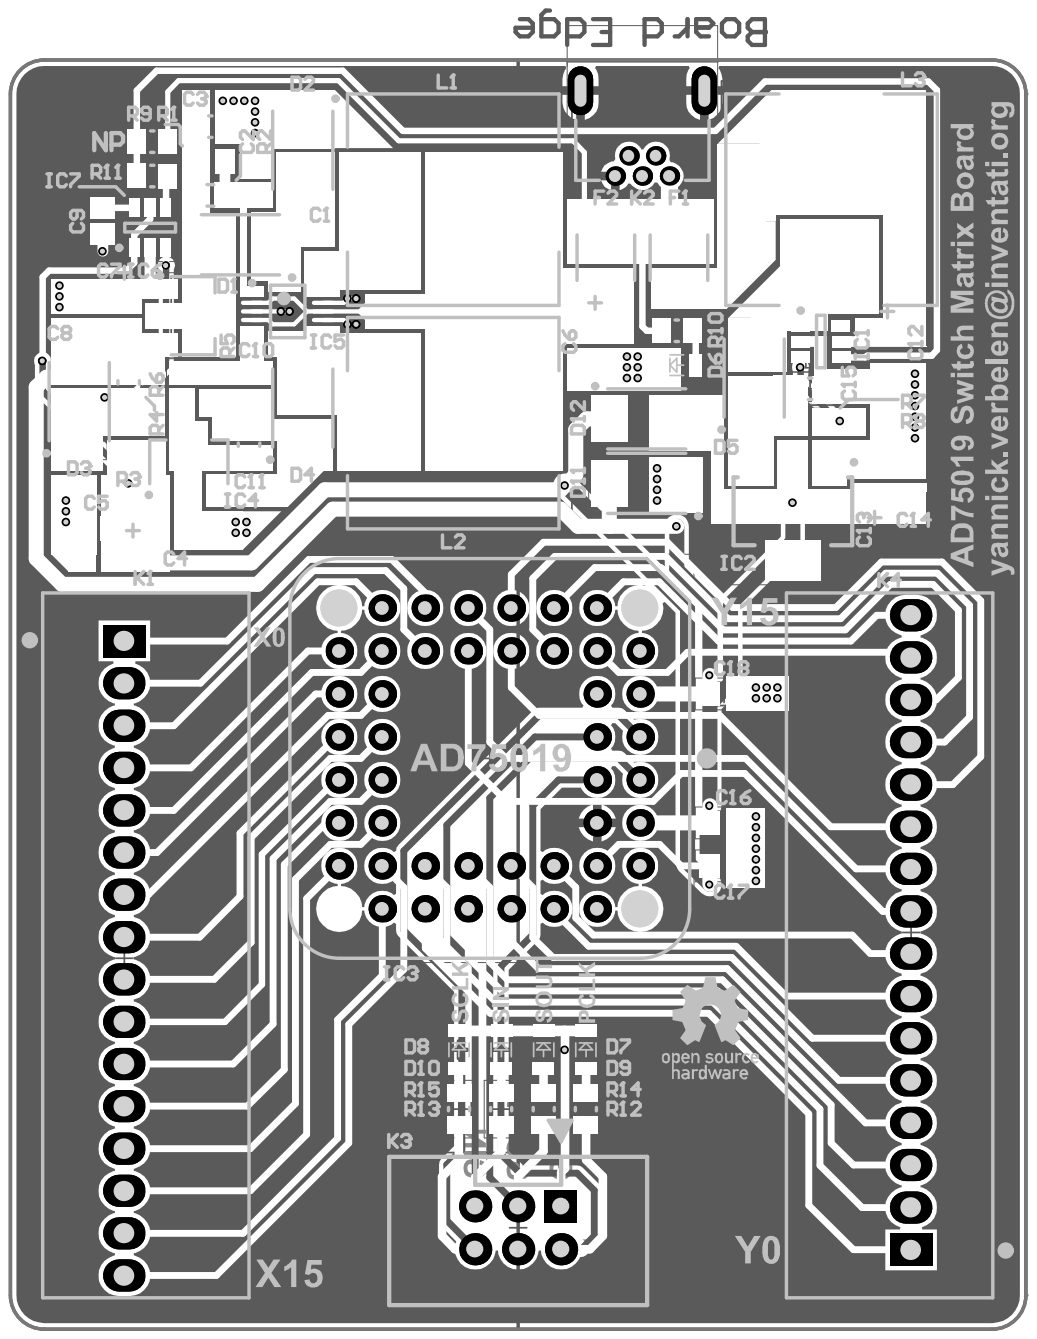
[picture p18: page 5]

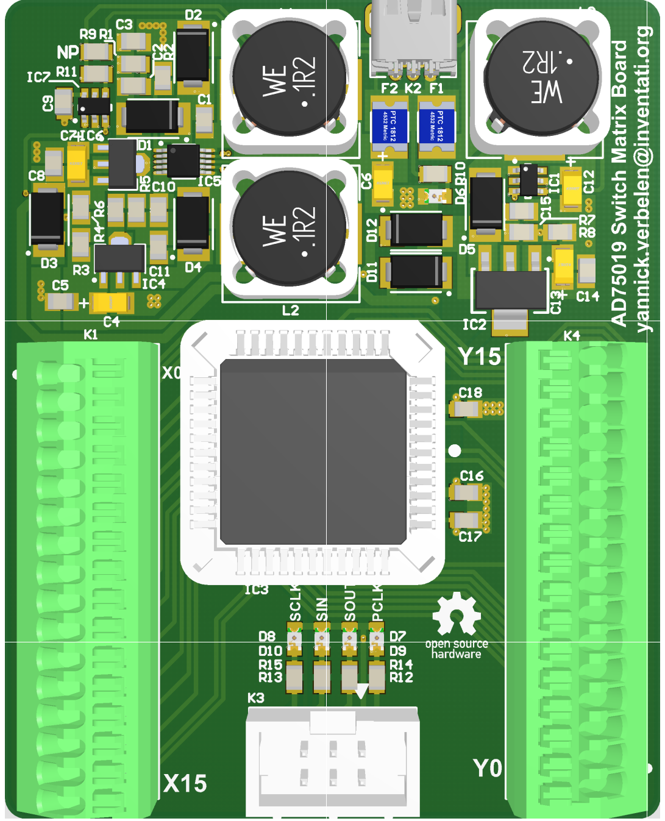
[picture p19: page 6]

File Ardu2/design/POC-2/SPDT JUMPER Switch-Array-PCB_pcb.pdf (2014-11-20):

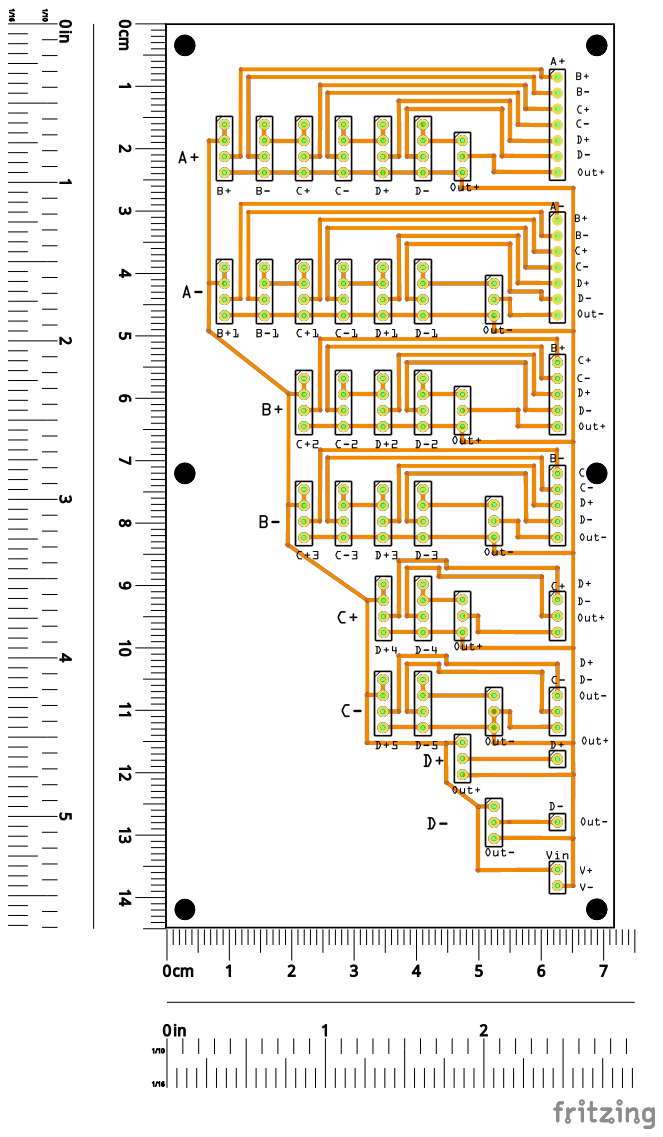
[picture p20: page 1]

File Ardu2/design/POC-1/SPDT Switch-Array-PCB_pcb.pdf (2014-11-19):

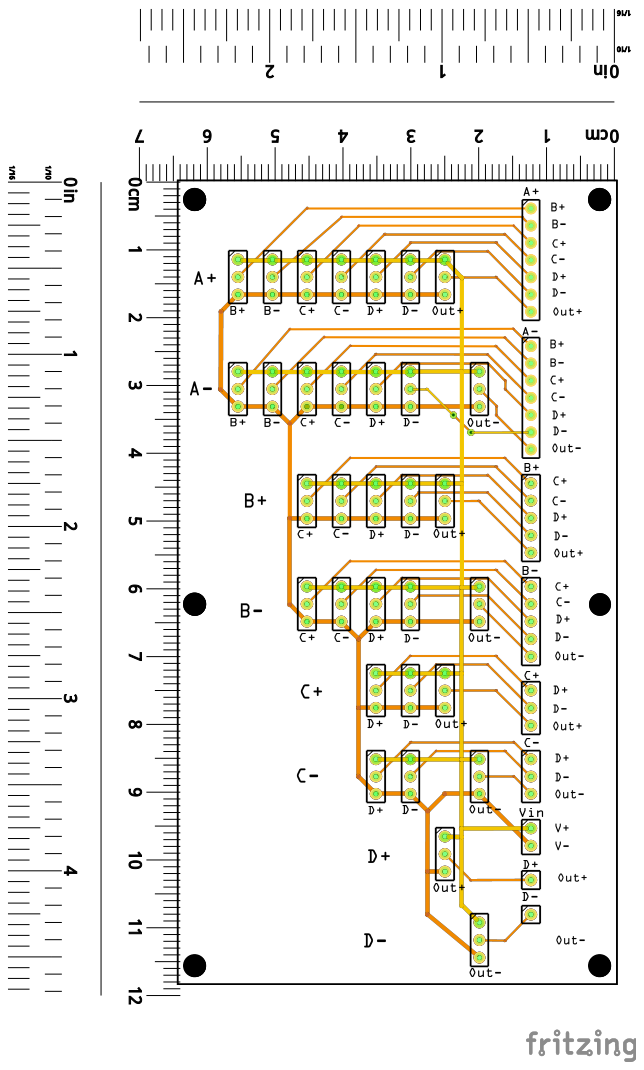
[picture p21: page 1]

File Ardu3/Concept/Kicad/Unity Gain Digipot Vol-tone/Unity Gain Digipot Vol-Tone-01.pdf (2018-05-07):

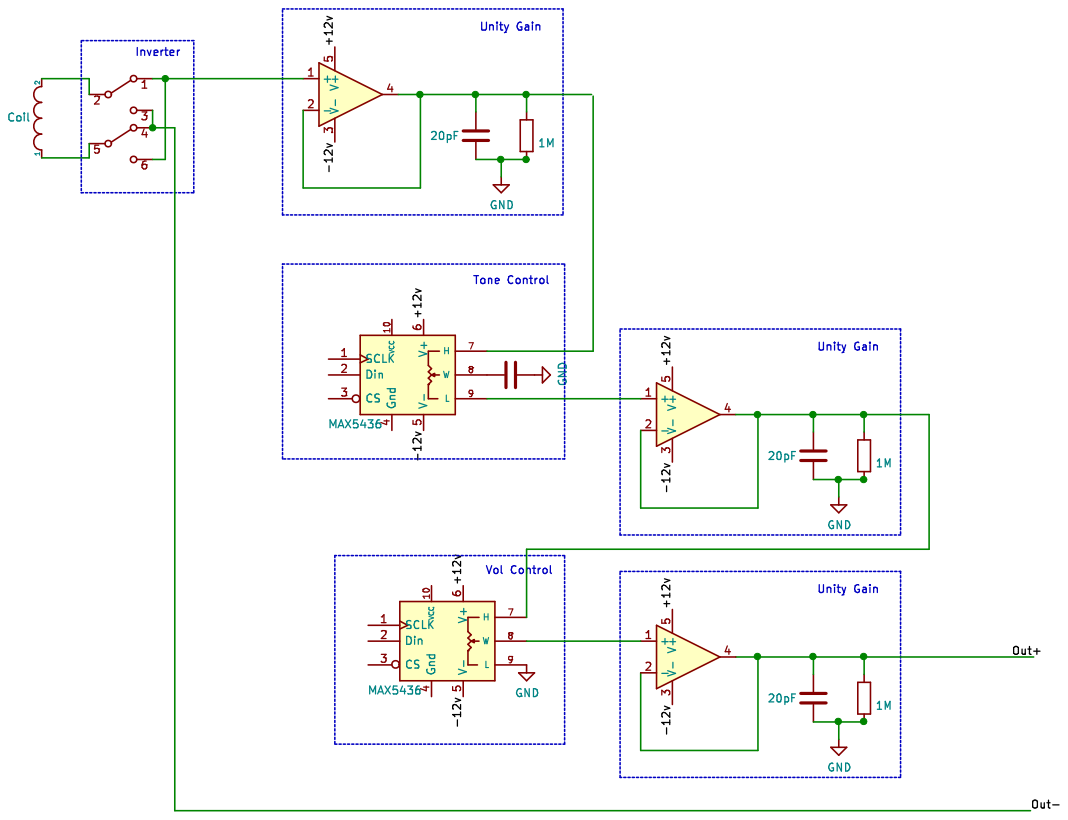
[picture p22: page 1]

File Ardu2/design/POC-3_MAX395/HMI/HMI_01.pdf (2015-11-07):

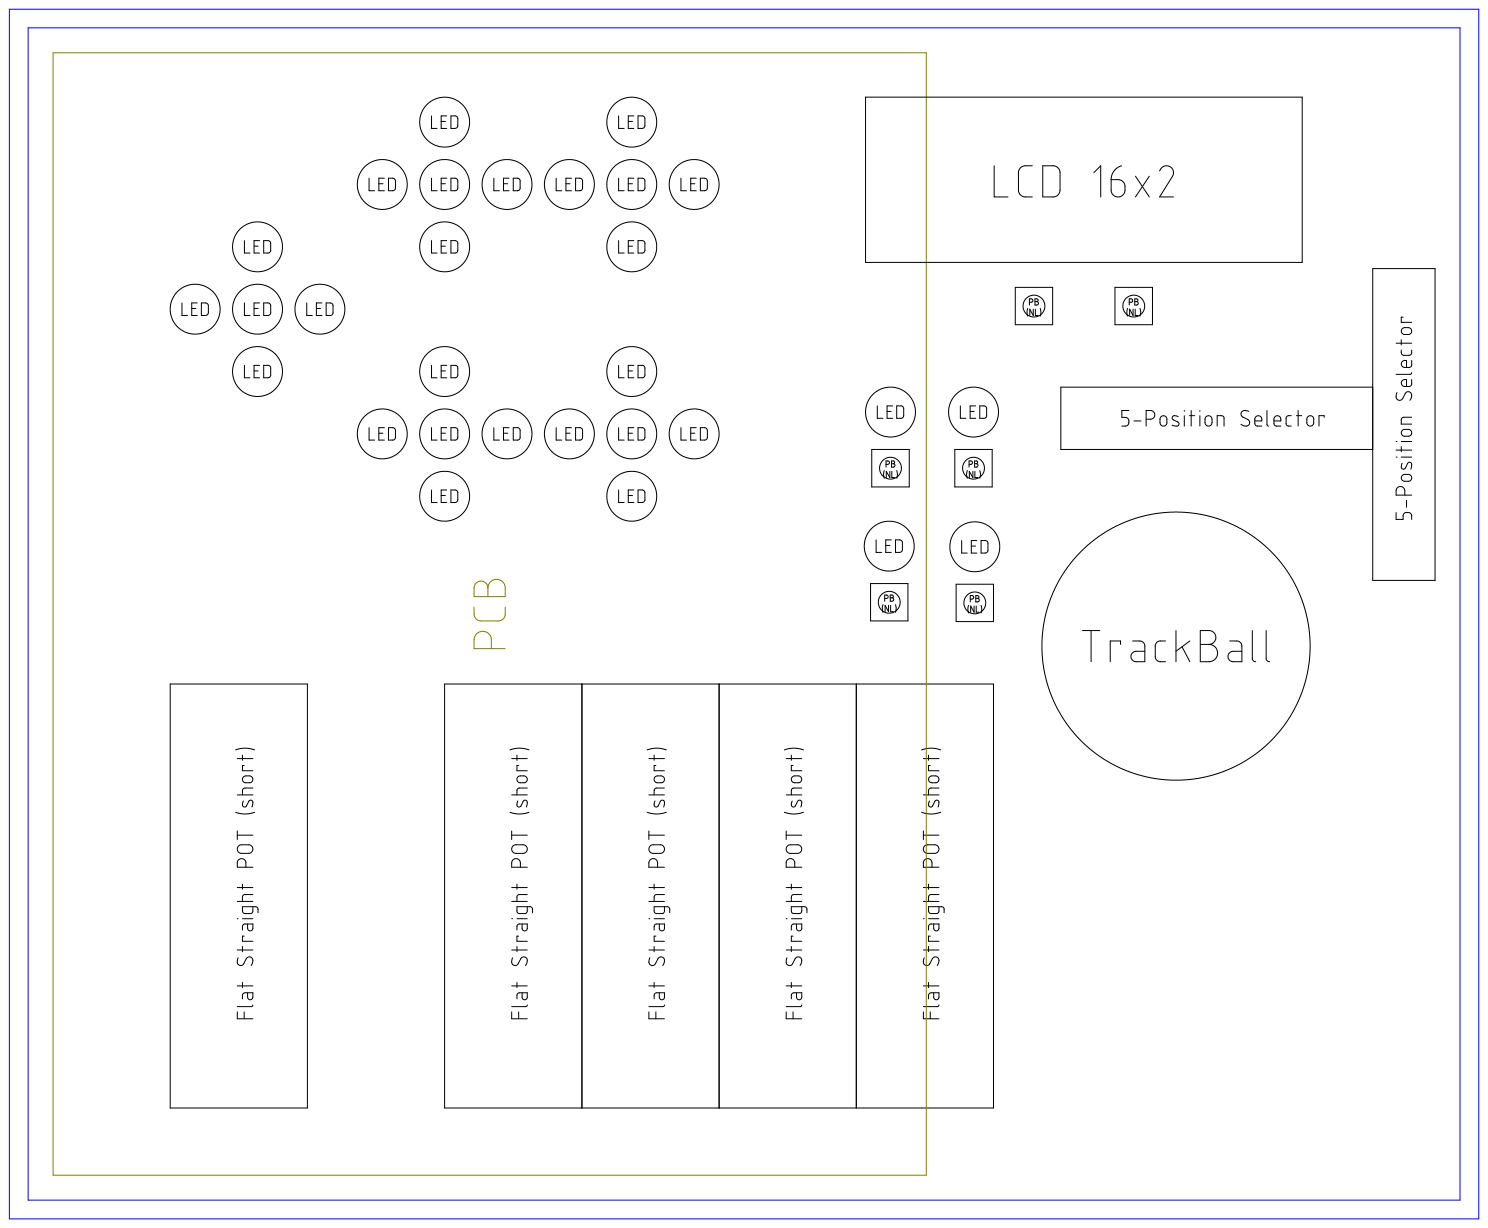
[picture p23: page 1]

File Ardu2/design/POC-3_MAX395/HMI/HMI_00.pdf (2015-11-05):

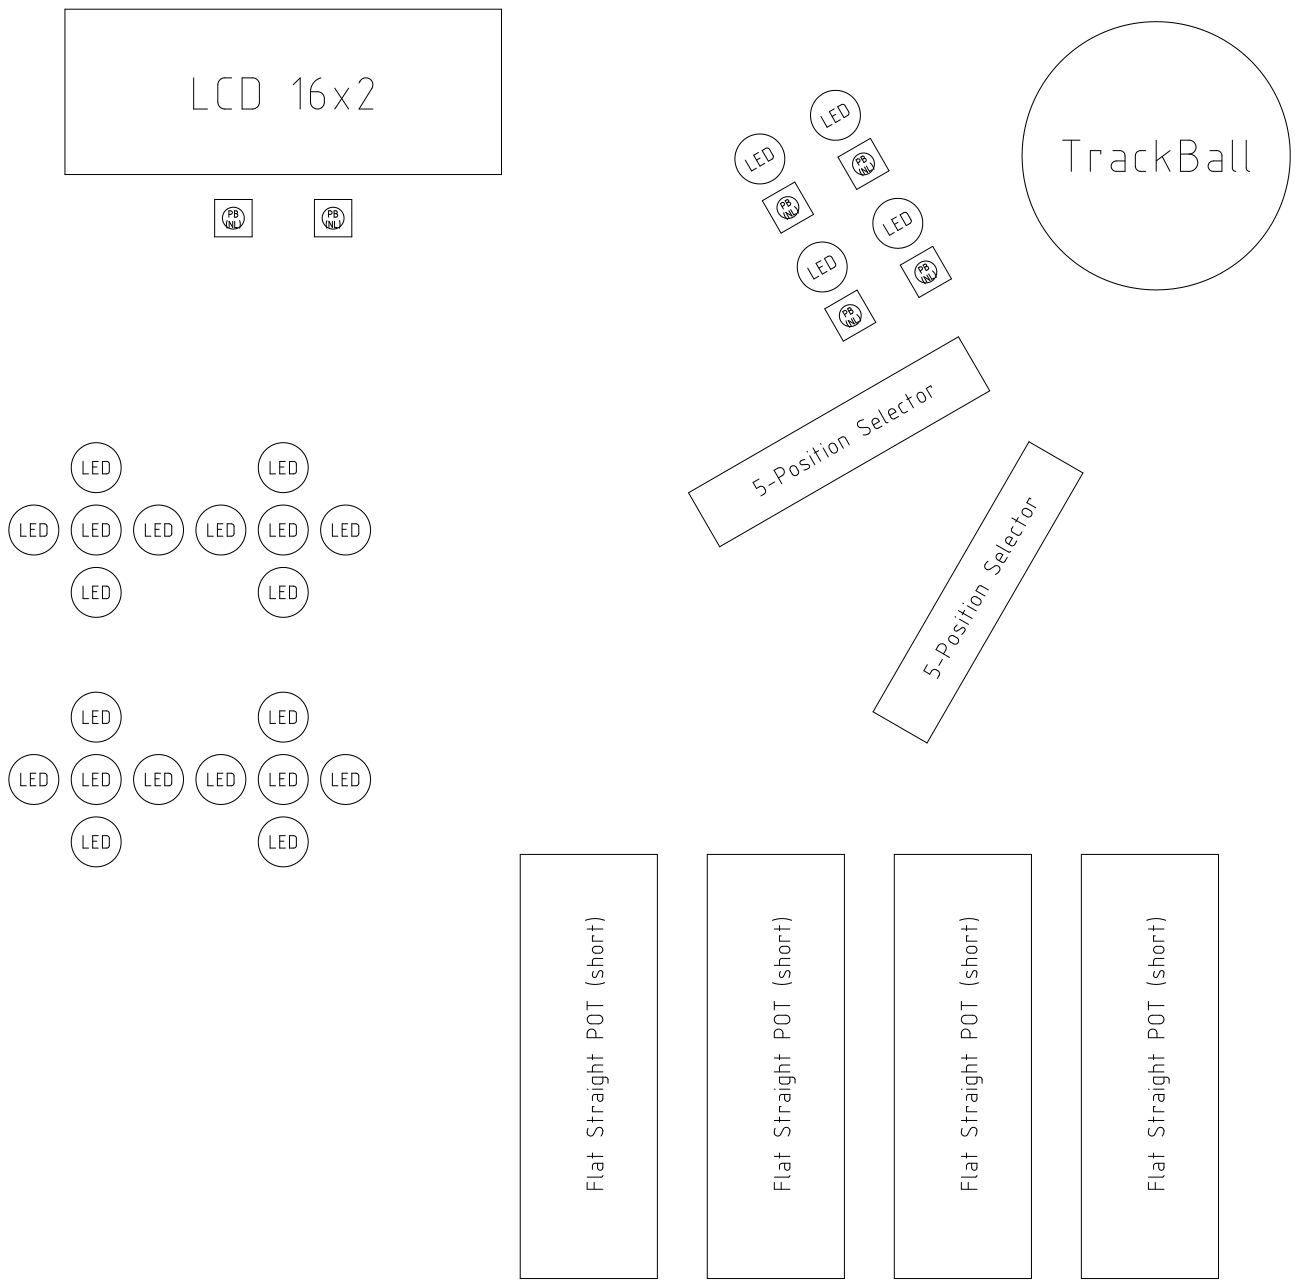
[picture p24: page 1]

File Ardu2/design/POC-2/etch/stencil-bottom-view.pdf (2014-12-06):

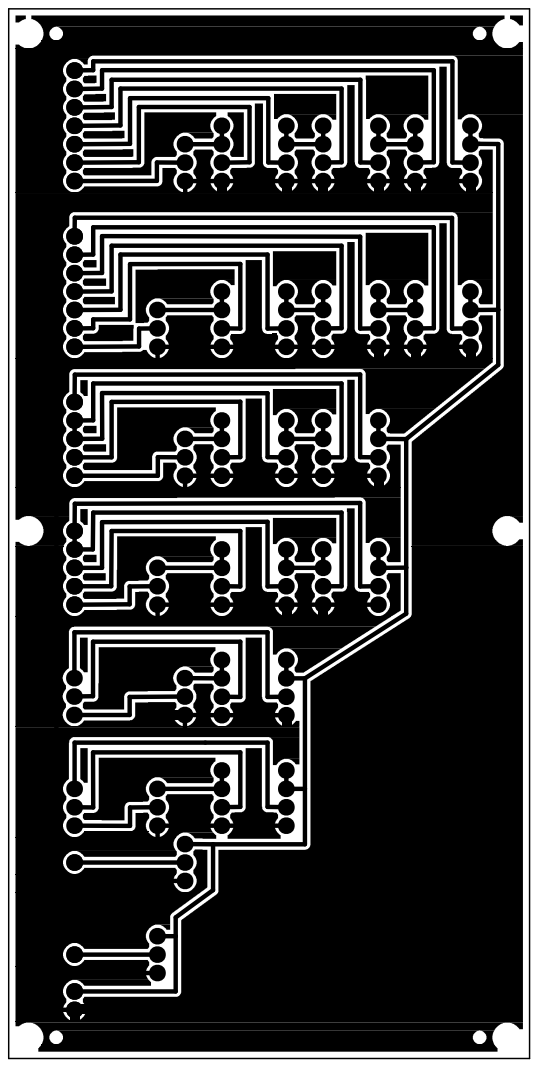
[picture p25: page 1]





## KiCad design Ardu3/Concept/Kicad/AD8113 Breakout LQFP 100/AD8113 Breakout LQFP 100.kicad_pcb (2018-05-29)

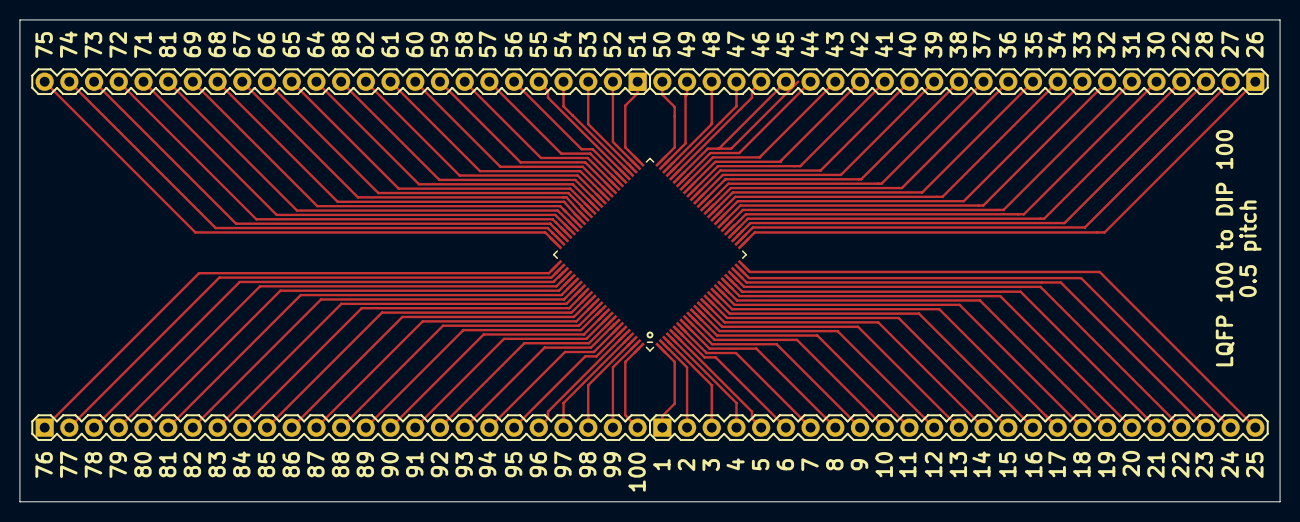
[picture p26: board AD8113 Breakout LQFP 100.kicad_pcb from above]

Board: 2 copper layers, 129.5 x 49.5 mm, 5 parts (0 on the bottom side), 100 nets.

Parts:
J1, J2, J3, J4: Conn_01x25_Male; 1X25
U1: AD8113JST; AD8113JSTZ

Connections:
/P001: J1.1, U1.1
/P002: J1.2, U1.2
/P003: J1.3, U1.3
/P004: J1.4, U1.4
/P005: J1.5, U1.5
/P006: J1.6, U1.6
/P007: J1.7, U1.7
/P008: J1.8, U1.8
/P009: J1.9, U1.9
/P010: J1.10, U1.10
/P011: J1.11, U1.11
/P012: J1.12, U1.12
/P013: J1.13, U1.13
/P014: J1.14, U1.14
/P015: J1.15, U1.15
/P016: J1.16, U1.16
/P017: J1.17, U1.17
/P018: J1.18, U1.18
/P019: J1.19, U1.19
/P020: J1.20, U1.20
/P021: J1.21, U1.21
/P022: J1.22, U1.22
/P023: J1.23, U1.23
/P024: J1.24, U1.24
/P025: J1.25, U1.25
/P026: J2.1, U1.26
/P027: J2.2, U1.27
/P028: J2.3, U1.28
/P029: J2.4, U1.29
/P030: J2.5, U1.30
/P031: J2.6, U1.31
/P032: J2.7, U1.32
/P033: J2.8, U1.33
/P034: J2.9, U1.34
/P035: J2.10, U1.35
/P036: J2.11, U1.36
/P037: J2.12, U1.37
/P038: J2.13, U1.38
/P039: J2.14, U1.39
/P040: J2.15, U1.40
/P041: J2.16, U1.41
/P042: J2.17, U1.42
/P043: J2.18, U1.43
/P044: J2.19, U1.44
/P045: J2.20, U1.45
/P046: J2.21, U1.46
/P047: J2.22, U1.47
/P048: J2.23, U1.48
/P049: J2.24, U1.49
/P050: J2.25, U1.50
/P051: J3.1, U1.51
/P052: J3.2, U1.52
/P053: J3.3, U1.53
/P054: J3.4, U1.54
/P055: J3.5, U1.55
/P056: J3.6, U1.56
/P057: J3.7, U1.57
/P058: J3.8, U1.58
/P059: J3.9, U1.59
/P060: J3.10, U1.60
/P061: J3.11, U1.61
/P062: J3.12, U1.62
/P063: J3.13, U1.63
/P064: J3.14, U1.64
/P065: J3.15, U1.65
/P066: J3.16, U1.66
/P067: J3.17, U1.67
/P068: J3.18, U1.68
/P069: J3.19, U1.69
/P070: J3.20, U1.70
/P071: J3.21, U1.71
/P072: J3.22, U1.72
/P073: J3.23, U1.73
/P074: J3.24, U1.74
/P075: J3.25, U1.75
/P076: J4.1, U1.76
/P077: J4.2, U1.77
/P078: J4.3, U1.78
/P079: J4.4, U1.79
/P080: J4.5, U1.80
/P081: J4.6, U1.81
/P082: J4.7, U1.82
/P083: J4.8, U1.83
/P084: J4.9, U1.84
/P085: J4.10, U1.85
/P086: J4.11, U1.86
/P087: J4.12, U1.87
/P088: J4.13, U1.88
/P089: J4.14, U1.89
/P090: J4.15, U1.90
/P091: J4.16, U1.91
/P092: J4.17, U1.92
/P093: J4.18, U1.93
/P094: J4.19, U1.94
/P095: J4.20, U1.95
/P096: J4.21, U1.96
/P097: J4.22, U1.97
/P098: J4.23, U1.98
/P099: J4.24, U1.99
/P100: J4.25, U1.100

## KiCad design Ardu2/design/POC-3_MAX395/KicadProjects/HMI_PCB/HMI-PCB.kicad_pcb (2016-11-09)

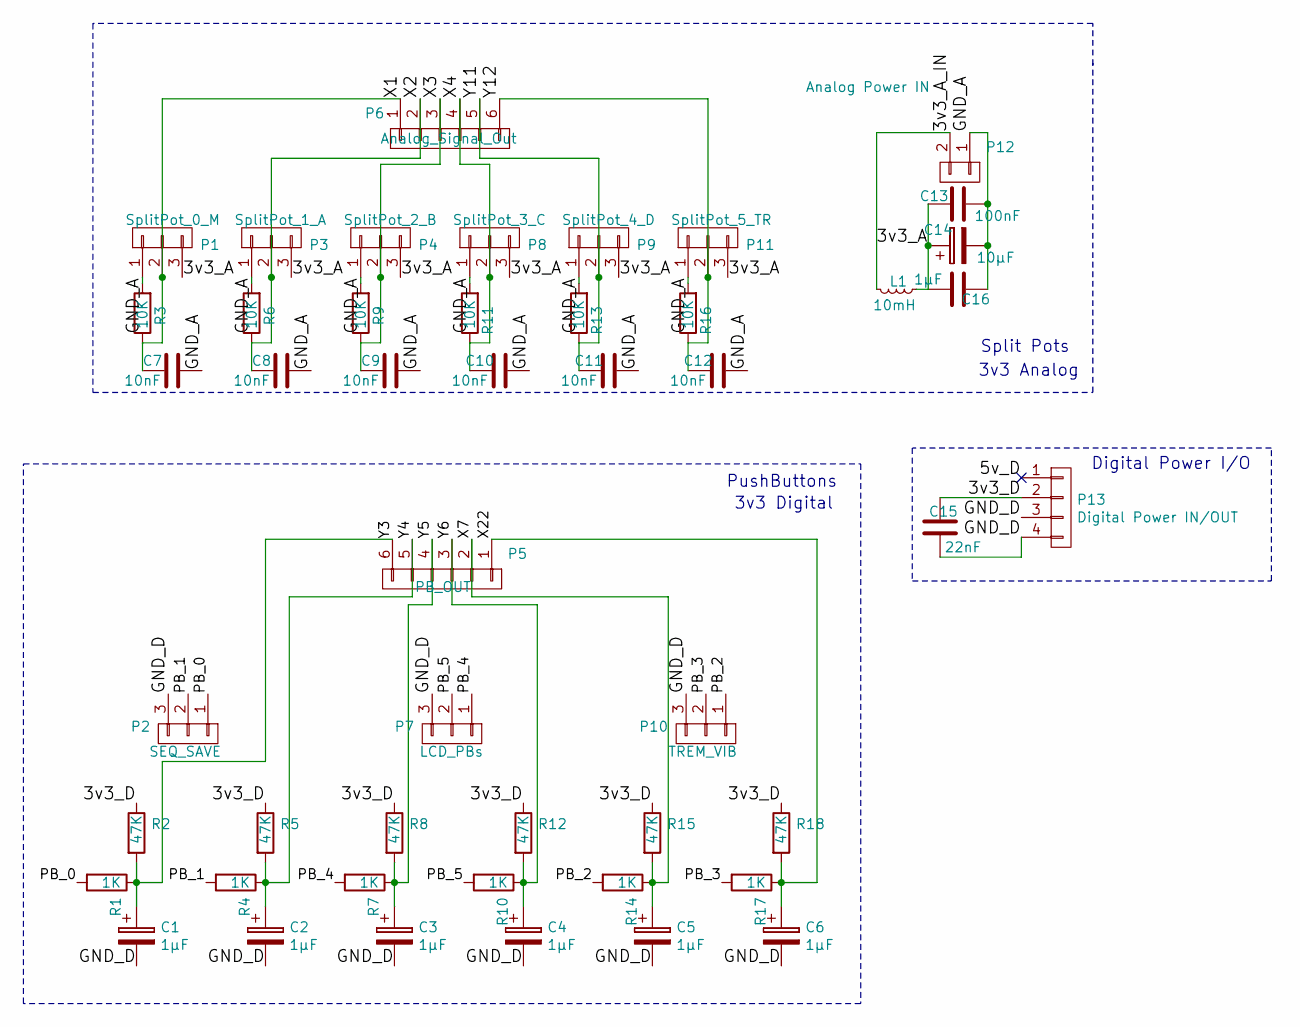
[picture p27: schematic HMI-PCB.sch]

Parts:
C1, C2, C3, C4, C5, C6: 1µF; C_Radial_D5_L11_P3.81
C7, C8, C9, C10, C11, C12: 10nF; C_Disc_D6_P5
C13: 100nF; C_Disc_D3_P2.5
C14: 10µF; C_Disc_D3_P2.5
C15: 22nF; C_Rect_L7_W2.5_P5
C16: 1µF; C_Disc_D3_P2.5
L1: 10mH; Choke_Radial_D13_P10_10mH
P1: SplitPot_0_M; Wafer_Angled_1x03_1mm_hole
P2: SEQ_SAVE; Wafer_Angled_1x03_1mm_hole
P3: SplitPot_1_A; Wafer_Angled_1x03_1mm_hole
P4: SplitPot_2_B; Wafer_Angled_1x03_1mm_hole
P5: PB_OUT; Wafer_Angled_1x06_1mm_Hole
P6: Analog_Signal_Out; Wafer_Angled_1x06_1mm_Hole
P7: LCD_PBs; Wafer_Angled_1x03_1mm_hole
P8: SplitPot_3_C; Wafer_Angled_1x03_1mm_hole
P9: SplitPot_4_D; Wafer_Angled_1x03_1mm_hole
P10: TREM_VIB; Wafer_Angled_1x03_1mm_hole
P11: SplitPot_5_TR; Wafer_Angled_1x03_1mm_hole
P12: Analog Power IN; Wafer_Angled_1x02_1mm_hole
P13: Digital Power IN/OUT; bornier4_Dinkle
R1, R4, R7, R10, R14, R17: 1K; Resistor_Horizontal_RM7mm_Big_Pads
R2, R5, R8, R12, R15, R18: 47K; Resistor_Horizontal_RM20mm_Big_Pads
R3, R6, R9, R11, R13, R16: 10K; Resistor_Horizontal_RM7mm_Big_Pads

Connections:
/3v3_A: C13.2, C14.1, C16.1, L1.1, P1.3, P3.3, P4.3, P8.3, P9.3, P11.3
/3v3_A_IN: L1.2, P12.2
/3v3_D: C15.1, P13.2, R2.1, R5.1, R8.1, R12.1, R15.1, R18.1
/GND_A: C7.1, C8.1, C9.1, C10.1, C11.1, C12.1, C13.1, C14.2, C16.2, P1.1, P3.1, P4.1, P8.1, P9.1, P11.1, P12.1, R3.2, R6.2, R9.2, R11.2, R13.2, R16.2
/GND_D: C1.2, C2.2, C3.2, C4.2, C5.2, C6.2, C15.2, P2.3, P7.3, P10.3, P13.3, P13.4
/PB_0: P2.1, R1.2
/PB_1: P2.2, R4.2
/PB_2: P10.1, R14.2
/PB_3: P10.2, R17.2
/PB_4: P7.1, R7.2
/PB_5: P7.2, R10.2
/X1: C7.2, P1.2, P6.1, R3.1
/X2: C8.2, P3.2, P6.2, R6.1
/X3: C9.2, P4.2, P6.3, R9.1
/X4: C10.2, P6.4, P8.2, R11.1
/X7: C5.1, P5.2, R14.1, R15.2
/X22: C6.1, P5.1, R17.1, R18.2
/Y3: C1.1, P5.6, R1.1, R2.2
/Y4: C2.1, P5.5, R4.1, R5.2
/Y5: C3.1, P5.4, R7.1, R8.2
/Y6: C4.1, P5.3, R10.1, R12.2
/Y11: C11.2, P6.5, P9.2, R13.1
/Y12: C12.2, P6.6, P11.2, R16.1

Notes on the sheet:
Split Pots
PushButtons
3v3 Digital
3v3 Analog
Digital Power I/O

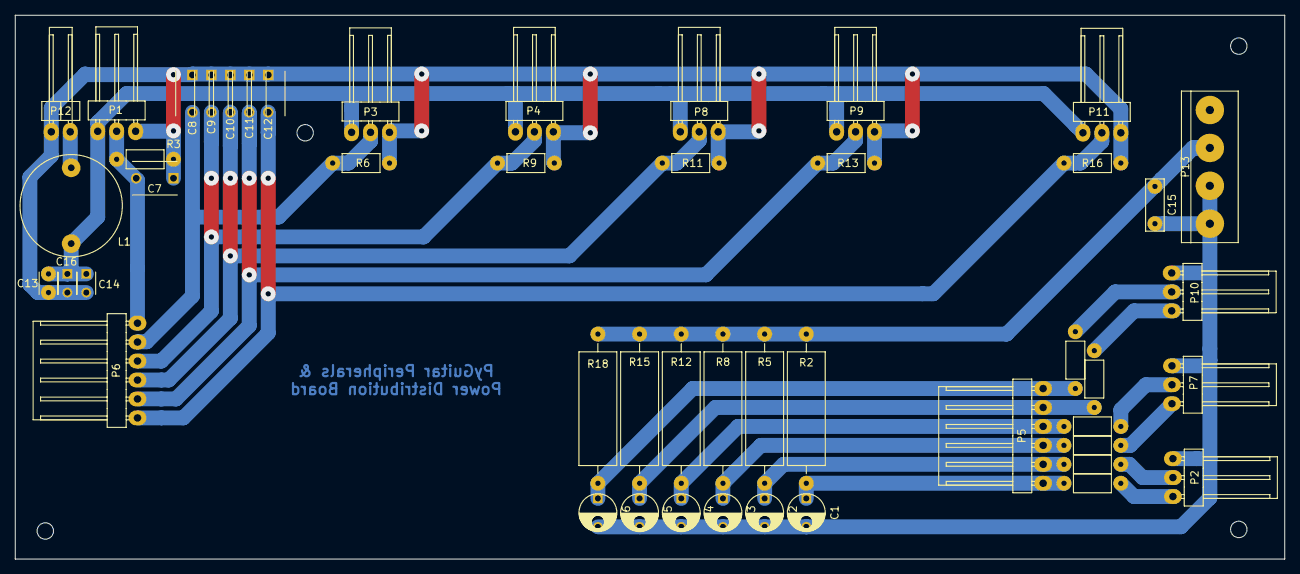
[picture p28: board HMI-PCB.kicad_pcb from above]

Board: 2 copper layers, 170.2 x 72.9 mm, 48 parts (0 on the bottom side), 23 nets.

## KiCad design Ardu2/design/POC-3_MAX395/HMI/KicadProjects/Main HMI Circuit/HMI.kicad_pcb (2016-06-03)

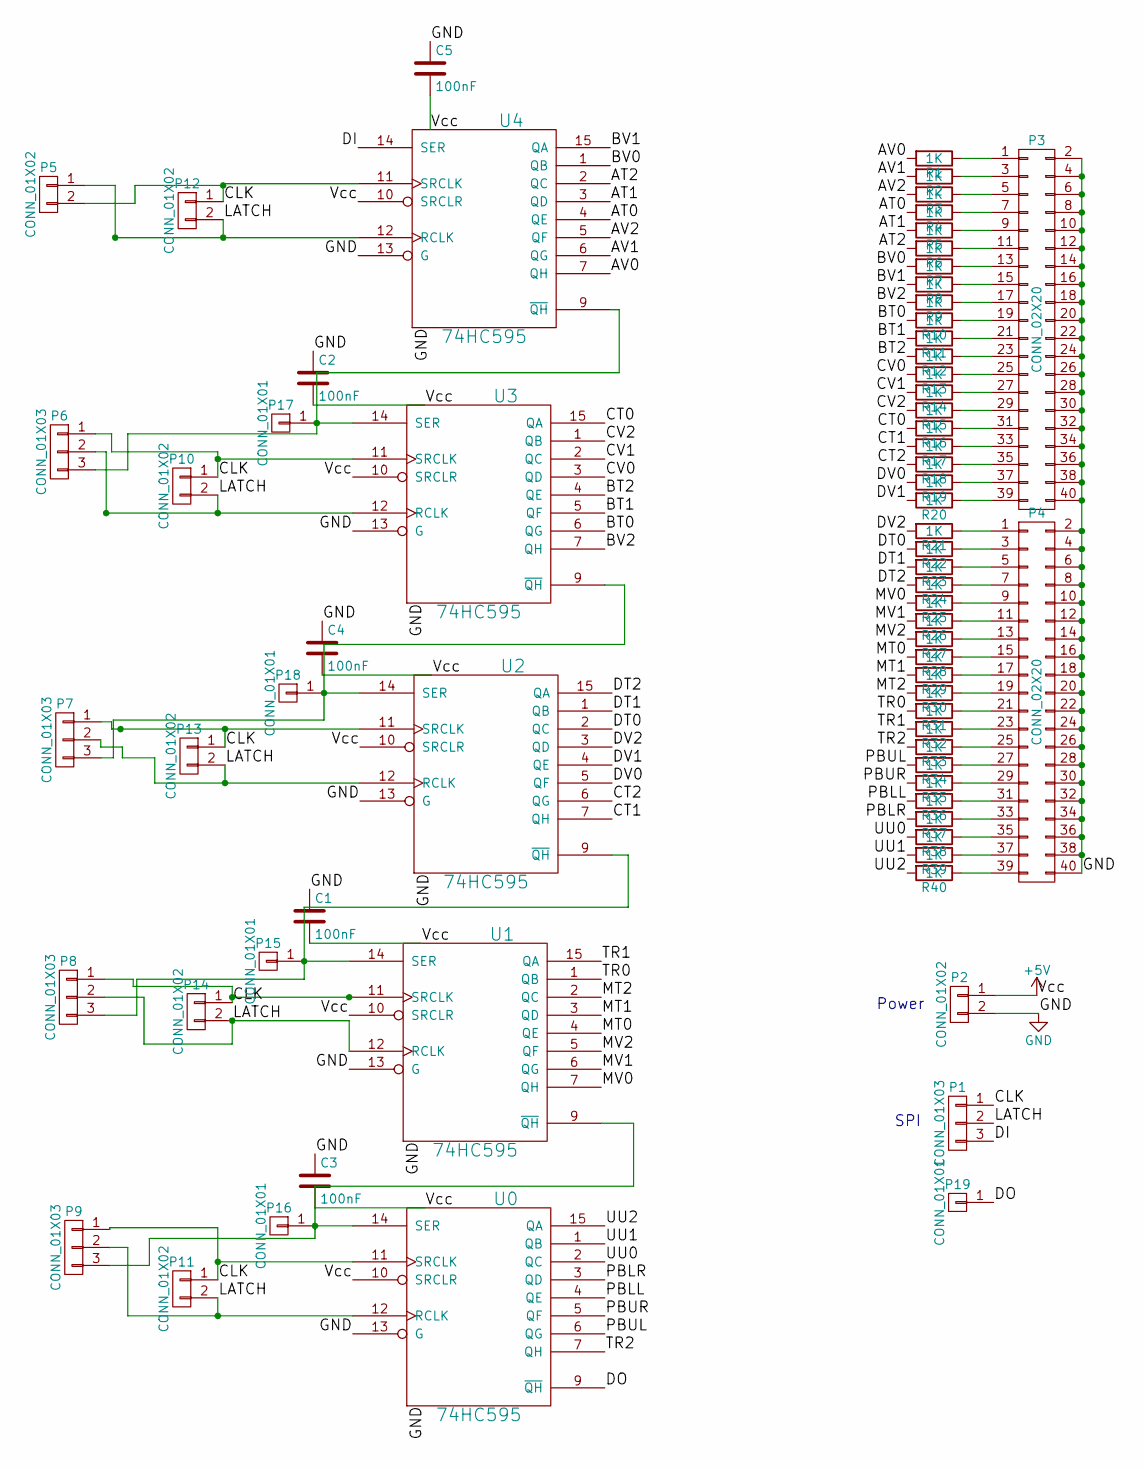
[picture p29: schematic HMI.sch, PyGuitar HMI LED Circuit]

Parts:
C1, C2, C3, C4, C5: 100nF; C_Disc_D3_P2.5
P1, P6, P7, P8, P9: CONN_01X03; Pin_Header_Straight_1x03
P2, P5, P10, P11, P12, P13, P14: CONN_01X02; Pin_Header_Straight_1x02
P3, P4: CONN_02X20; Pin_Header_Straight_2x20
P15, P16, P17, P18, P19: CONN_01X01; Pin_Header_Straight_1x01
R1, R2, R3, R4, R5, R6, R7, R8, R9, R10, R11, R12, R13, R14, R15, R16, R17, R18, R19, R20, R21, R22, R23, R24, R25, R26, R27, R28, R29, R30, R31, R32, R33, R34, R35, R36, R37, R38, R39, R40: 1K; Resistor_Horizontal_RM10mm
U0, U1, U2, U3, U4: 74HC595; DIP-16_W7.62mm

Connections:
+5V: C1.2, C2.2, C3.2, C4.2, C5.2, P2.1, U0.10 (SRCLR), U0.16 (VCC), U1.10 (SRCLR), U1.16 (VCC), U2.10 (SRCLR), U2.16 (VCC), U3.10 (SRCLR), U3.16 (VCC), U4.10 (SRCLR), U4.16 (VCC)
/AT0: R4.2, U4.4 (QE)
/AT1: R5.2, U4.3 (QD)
/AT2: R6.2, U4.2 (QC)
/AV0: R1.2, U4.7 (QH)
/AV1: R2.2, U4.6 (QG)
/AV2: R3.2, U4.5 (QF)
/BT0: R10.2, U3.6 (QG)
/BT1: R11.2, U3.5 (QF)
/BT2: R12.2, U3.4 (QE)
/BV0: R7.2, U4.1 (QB)
/BV1: R8.2, U4.15 (QA)
/BV2: R9.2, U3.7 (QH)
/CLK: P1.1, P5.2, P6.1, P7.1, P8.1, P9.1, P10.1, P11.1, P12.1, P13.1, P14.1, U0.11 (SRCLK), U1.11 (SRCLK), U2.11 (SRCLK), U3.11 (SRCLK), U4.11 (SRCLK)
/CT0: R16.2, U3.15 (QA)
/CT1: R17.2, U2.7 (QH)
/CT2: R18.2, U2.6 (QG)
/CV0: R13.2, U3.3 (QD)
/CV1: R14.2, U3.2 (QC)
/CV2: R15.2, U3.1 (QB)
/DI: P1.3, U4.14 (SER)
/DO: P19.1, U0.9 (~QH)
/DT0: R22.2, U2.2 (QC)
/DT1: R23.2, U2.1 (QB)
/DT2: R24.2, U2.15 (QA)
/DV0: R19.2, U2.5 (QF)
/DV1: R20.2, U2.4 (QE)
/DV2: R21.2, U2.3 (QD)
/LATCH: P1.2, P5.1, P6.2, P7.2, P8.2, P9.2, P10.2, P11.2, P12.2, P13.2, P14.2, U0.12 (RCLK), U1.12 (RCLK), U2.12 (RCLK), U3.12 (RCLK), U4.12 (RCLK)
/MT0: R28.2, U1.4 (QE)
/MT1: R29.2, U1.3 (QD)
/MT2: R30.2, U1.2 (QC)
/MV0: R25.2, U1.7 (QH)
/MV1: R26.2, U1.6 (QG)
/MV2: R27.2, U1.5 (QF)
/PBLL: R36.2, U0.4 (QE)
/PBLR: R37.2, U0.3 (QD)
/PBUL: R34.2, U0.6 (QG)
/PBUR: R35.2, U0.5 (QF)
/TR0: R31.2, U1.1 (QB)
/TR1: R32.2, U1.15 (QA)
/TR2: R33.2, U0.7 (QH)
/UU0: R38.2, U0.2 (QC)
/UU1: R39.2, U0.1 (QB)
/UU2: R40.2, U0.15 (QA)
GND: C1.1, C2.1, C3.1, C4.1, C5.1, P2.2, P3.2, P3.4, P3.6, P3.8, P3.10, P3.12, P3.14, P3.16, P3.18, P3.20, P3.22, P3.24, P3.26, P3.28, P3.30, P3.32, P3.34, P3.36, P3.38, P3.40, P4.2, P4.4, P4.6, P4.8, P4.10, P4.12, P4.14, P4.16, P4.18, P4.20, P4.22, P4.24, P4.26, P4.28, P4.30, P4.32, P4.34, P4.36, P4.38, P4.40, U0.8 (GND), U0.13 (G), U1.8 (GND), U1.13 (G), U2.8 (GND), U2.13 (G), U3.8 (GND), U3.13 (G), U4.8 (GND), U4.13 (G)
unnamed: P3.1, R1.1
unnamed: P3.3, R2.1
unnamed: P3.5, R3.1
unnamed: P3.7, R4.1
unnamed: P3.9, R5.1
unnamed: P3.11, R6.1
unnamed: P3.13, R7.1
unnamed: P3.15, R8.1
unnamed: P3.17, R9.1
unnamed: P3.19, R10.1
unnamed: P3.21, R11.1
unnamed: P3.23, R12.1
unnamed: P3.25, R13.1
unnamed: P3.27, R14.1
unnamed: P3.29, R15.1
unnamed: P3.31, R16.1
unnamed: P3.33, R17.1
unnamed: P3.35, R18.1
unnamed: P3.37, R19.1
unnamed: P3.39, R20.1
unnamed: P4.1, R21.1
unnamed: P4.3, R22.1
unnamed: P4.5, R23.1
unnamed: P4.7, R24.1
unnamed: P4.9, R25.1
unnamed: P4.11, R26.1
unnamed: P4.13, R27.1
unnamed: P4.15, R28.1
unnamed: P4.17, R29.1
unnamed: P4.19, R30.1
unnamed: P4.21, R31.1
unnamed: P4.23, R32.1
unnamed: P4.25, R33.1
unnamed: P4.27, R34.1
unnamed: P4.29, R35.1
unnamed: P4.31, R36.1
unnamed: P4.33, R37.1
unnamed: P4.35, R38.1
unnamed: P4.37, R39.1
unnamed: P4.39, R40.1
unnamed: P8.3, P15.1, U1.14 (SER), U2.9 (~QH)
unnamed: P9.3, P16.1, U0.14 (SER), U1.9 (~QH)
unnamed: P6.3, P17.1, U3.14 (SER), U4.9 (~QH)
unnamed: P7.3, P18.1, U2.14 (SER), U3.9 (~QH)

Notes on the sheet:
Power
SPI

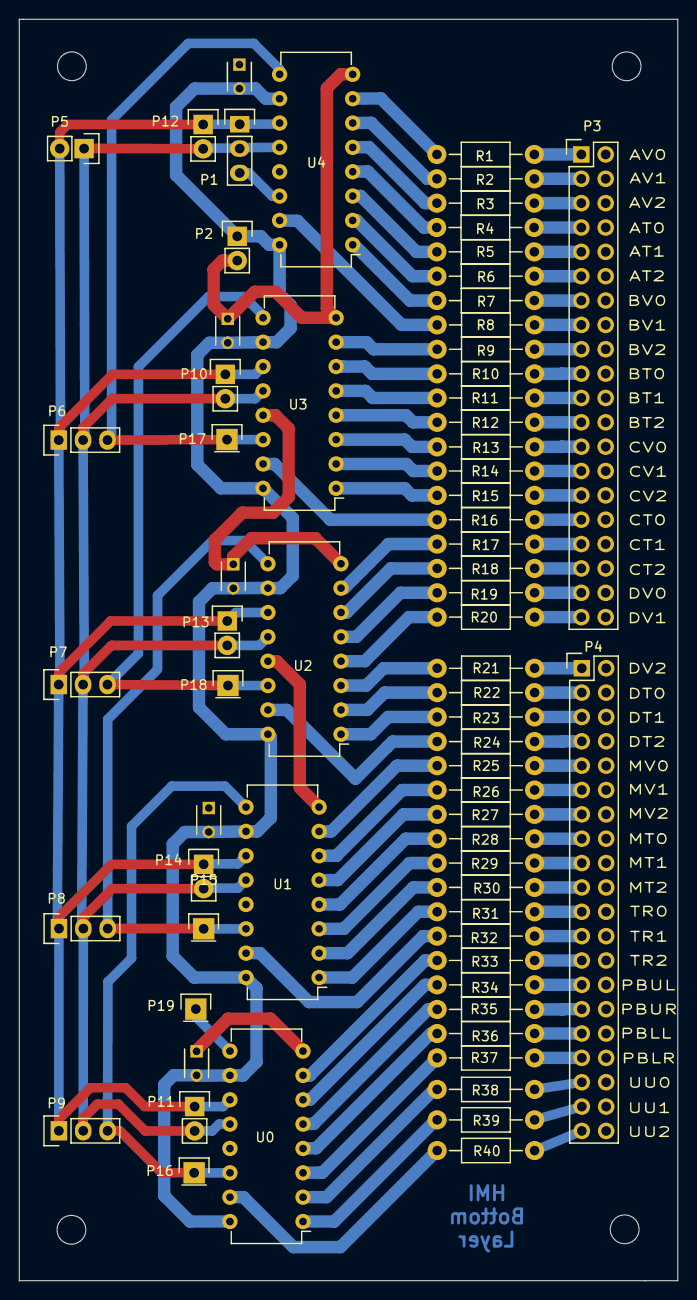
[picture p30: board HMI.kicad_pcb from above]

Board: 2 copper layers, 68.7 x 131.6 mm, 73 parts (0 on the bottom side), 90 nets.

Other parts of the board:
H0, H1, H2, H3: MountingHole_3mm

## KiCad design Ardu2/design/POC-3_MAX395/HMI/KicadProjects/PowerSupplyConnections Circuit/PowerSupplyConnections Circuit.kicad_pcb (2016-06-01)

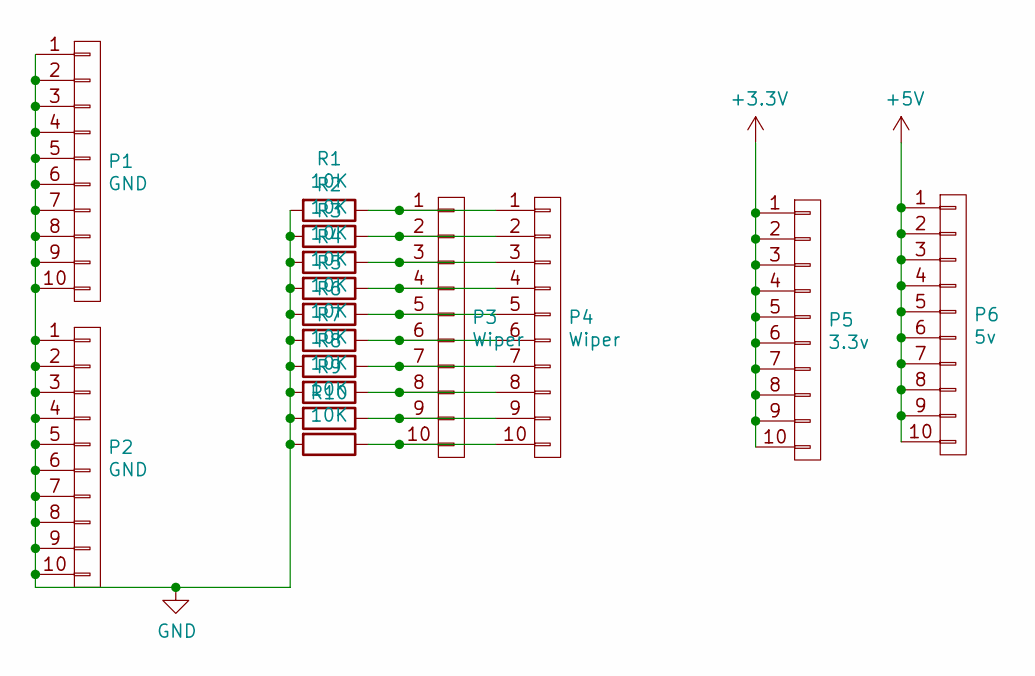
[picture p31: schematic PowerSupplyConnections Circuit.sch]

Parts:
P1, P2: GND; Pin_Header_Straight_1x10
P3, P4: Wiper; Pin_Header_Straight_1x10
P5: 3.3v; Pin_Header_Straight_1x10
P6: 5v; Pin_Header_Straight_1x10
R1, R2, R3, R4, R5, R6, R7, R8, R9, R10: 10K; Resistor_Horizontal_RM10mm

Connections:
+3V3: P5.1, P5.2, P5.3, P5.4, P5.5, P5.6, P5.7, P5.8, P5.9, P5.10
+5V: P6.1, P6.2, P6.3, P6.4, P6.5, P6.6, P6.7, P6.8, P6.9, P6.10
GND: P1.1, P1.2, P1.3, P1.4, P1.5, P1.6, P1.7, P1.8, P1.9, P1.10, P2.1, P2.2, P2.3, P2.4, P2.5, P2.6, P2.7, P2.8, P2.9, P2.10, R1.2, R2.2, R3.2, R4.2, R5.2, R6.2, R7.2, R8.2, R9.2, R10.2
unnamed: P3.1, P4.1, R1.1
unnamed: P3.2, P4.2, R2.1
unnamed: P3.3, P4.3, R3.1
unnamed: P3.4, P4.4, R4.1
unnamed: P3.5, P4.5, R5.1
unnamed: P3.6, P4.6, R6.1
unnamed: P3.7, P4.7, R7.1
unnamed: P3.8, P4.8, R8.1
unnamed: P3.9, P4.9, R9.1
unnamed: P3.10, P4.10, R10.1

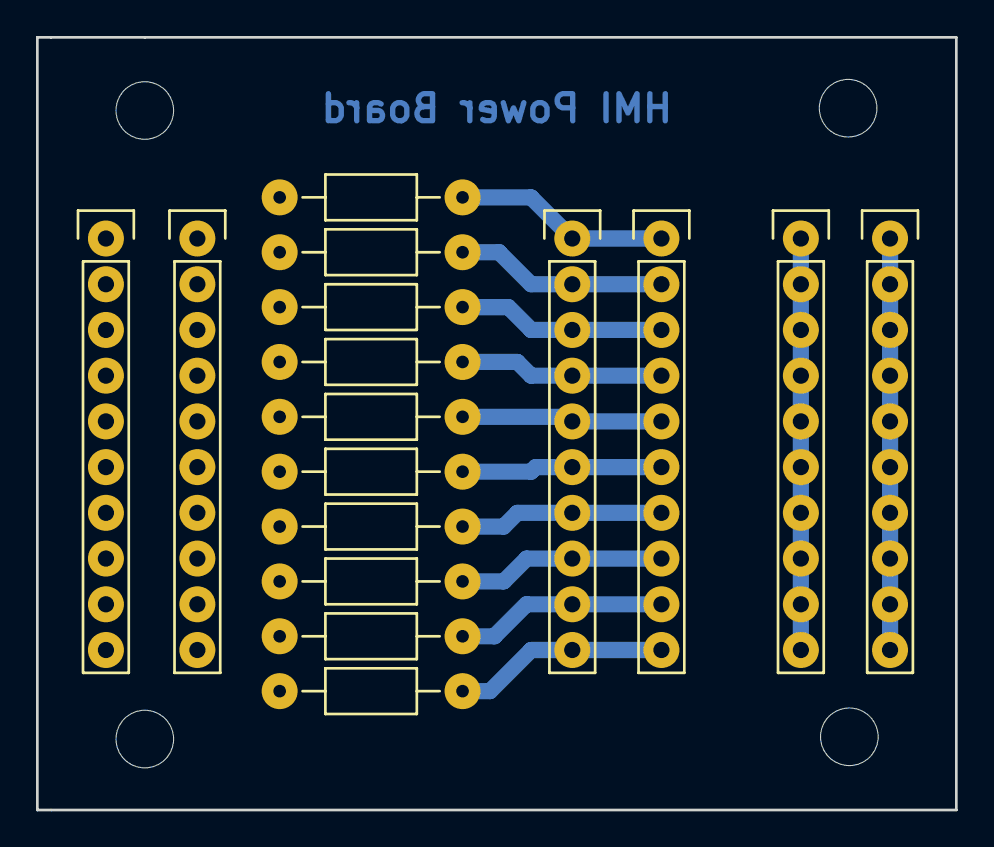
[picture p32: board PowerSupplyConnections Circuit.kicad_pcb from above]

Board: 2 copper layers, 51.1 x 42.9 mm, 16 parts (0 on the bottom side), 13 nets.

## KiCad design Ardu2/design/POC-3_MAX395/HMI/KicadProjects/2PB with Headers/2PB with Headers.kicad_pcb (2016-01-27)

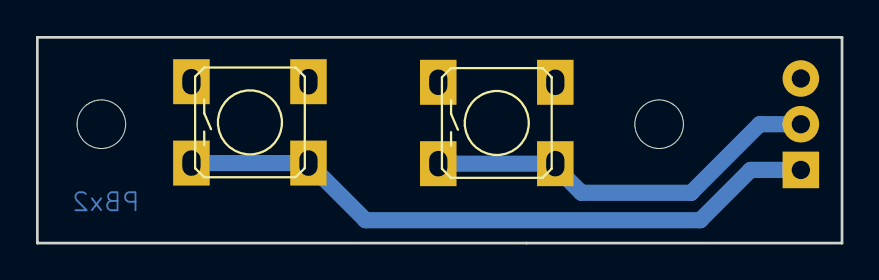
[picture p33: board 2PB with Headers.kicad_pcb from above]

Board: 2 copper layers, 44.7 x 11.4 mm, 3 parts (1 on the bottom side), 3 nets.

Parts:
GND P2 P1: CONN_01X03; Pin_Header_Straight_1x03
SW1, SW2: SW_PUSH; AB2_PB_MOM_6MM_PTH_BLK

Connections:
GND: GND P2 P1.3, SW1.1, SW2.1
unnamed: GND P2 P1.1, SW1.2
unnamed: GND P2 P1.2, SW2.2

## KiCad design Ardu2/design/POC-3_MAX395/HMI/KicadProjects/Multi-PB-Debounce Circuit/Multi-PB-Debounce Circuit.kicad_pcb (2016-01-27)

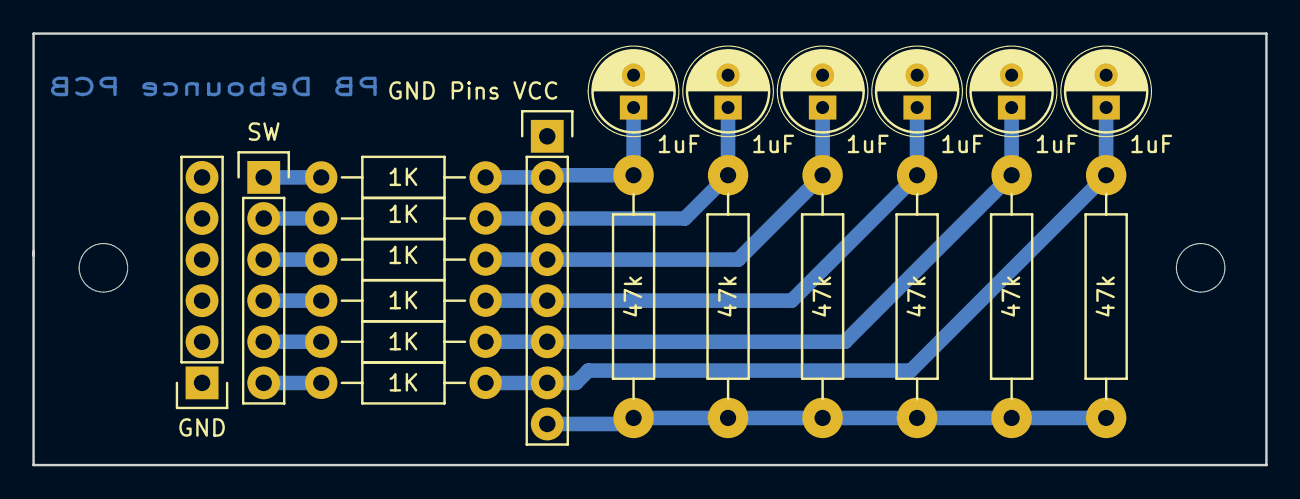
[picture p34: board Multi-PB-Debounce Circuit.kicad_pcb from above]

Board: 2 copper layers, 76.2 x 26.7 mm, 21 parts (0 on the bottom side), 14 nets.

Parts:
C1, C2, C3, C4, C5, C6: 1uF; C_Radial_D5_L11_P2
GND: CONN_01X06; Pin_Header_Straight_1x06
GND Pins VCC: CONN_01X08; Pin_Header_Straight_1x08
R1, R2, R5, R7, R9, R11: 1K; Resistor_Horizontal_RM10mm
R3, R4, R6, R8, R10, R12: 47k; Resistor_Horizontal_RM15mm
SW: CONN_01X06; Pin_Header_Straight_1x06

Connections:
/Pin0: C2.1, GND Pins VCC.2, R1.1, R4.2
/Pin1: C3.1, GND Pins VCC.3, R5.1, R6.2
/Pin2: C4.1, GND Pins VCC.4, R7.1, R8.2
/Pin3: C5.1, GND Pins VCC.5, R9.1, R10.2
/Pin4: C6.1, GND Pins VCC.6, R11.1, R12.2
/Pin5: C1.1, GND Pins VCC.7, R2.1, R3.2
/SW0: R1.2, SW.1
/SW1: R5.2, SW.2
/SW2: R7.2, SW.3
/SW3: R9.2, SW.4
/SW4: R11.2, SW.5
/SW5: R2.2, SW.6
GND: C1.2, C2.2, C3.2, C4.2, C5.2, C6.2, GND.1, GND.2, GND.3, GND.4, GND.5, GND.6, GND Pins VCC.1
VCC: GND Pins VCC.8, R3.1, R4.1, R6.1, R8.1, R10.1, R12.1

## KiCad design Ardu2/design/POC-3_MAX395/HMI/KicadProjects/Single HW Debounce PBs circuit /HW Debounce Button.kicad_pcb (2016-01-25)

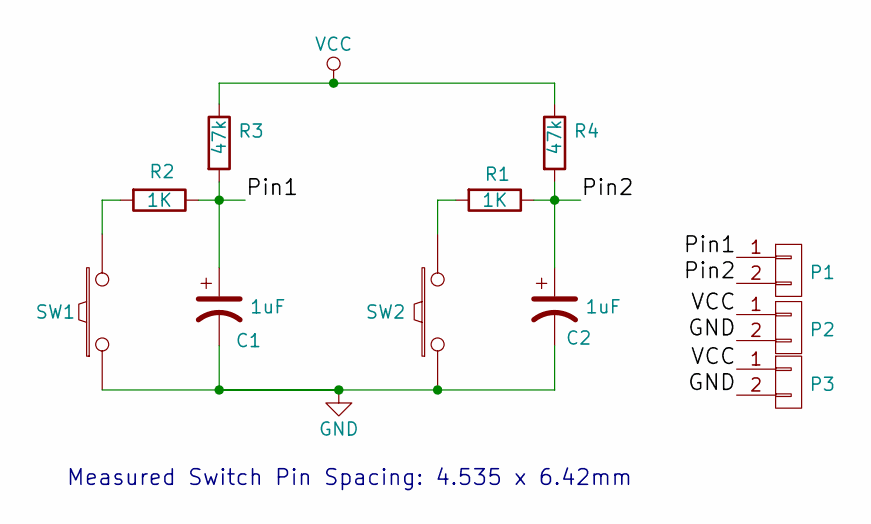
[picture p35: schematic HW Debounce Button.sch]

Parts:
C1, C2: 1uF; C_Radial_D5_L11_P2
P1, P2, P3: CONN_01X02; Pin_Header_Straight_1x02
R1, R2: 1K; Resistor_Horizontal_RM10mm
R3, R4: 47k; Resistor_Horizontal_RM10mm
SW1, SW2: SW_PUSH; AB2_PB_MOM_6MM_PTH_BLK

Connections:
/Pin1: C1.1, P1.1, R2.1, R3.2
/Pin2: C2.1, P1.2, R1.1, R4.2
GND: C1.2, C2.2, P2.2, P3.2, SW1.1, SW2.1
unnamed: R1.2, SW2.2
unnamed: R2.2, SW1.2
VCC: P2.1, P3.1, R3.1, R4.1

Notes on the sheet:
Measured Switch Pin Spacing: 4.535 x 6.42mm

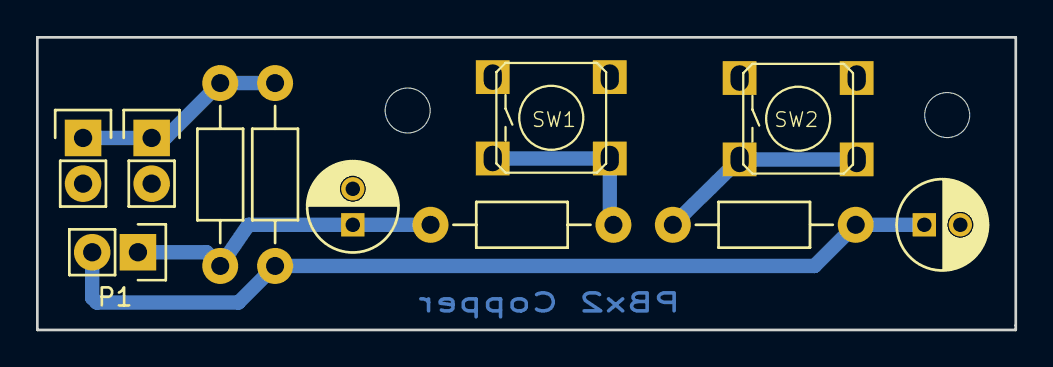
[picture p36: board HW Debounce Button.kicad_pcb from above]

Board: 2 copper layers, 54.4 x 16.3 mm, 11 parts (0 on the bottom side), 6 nets.

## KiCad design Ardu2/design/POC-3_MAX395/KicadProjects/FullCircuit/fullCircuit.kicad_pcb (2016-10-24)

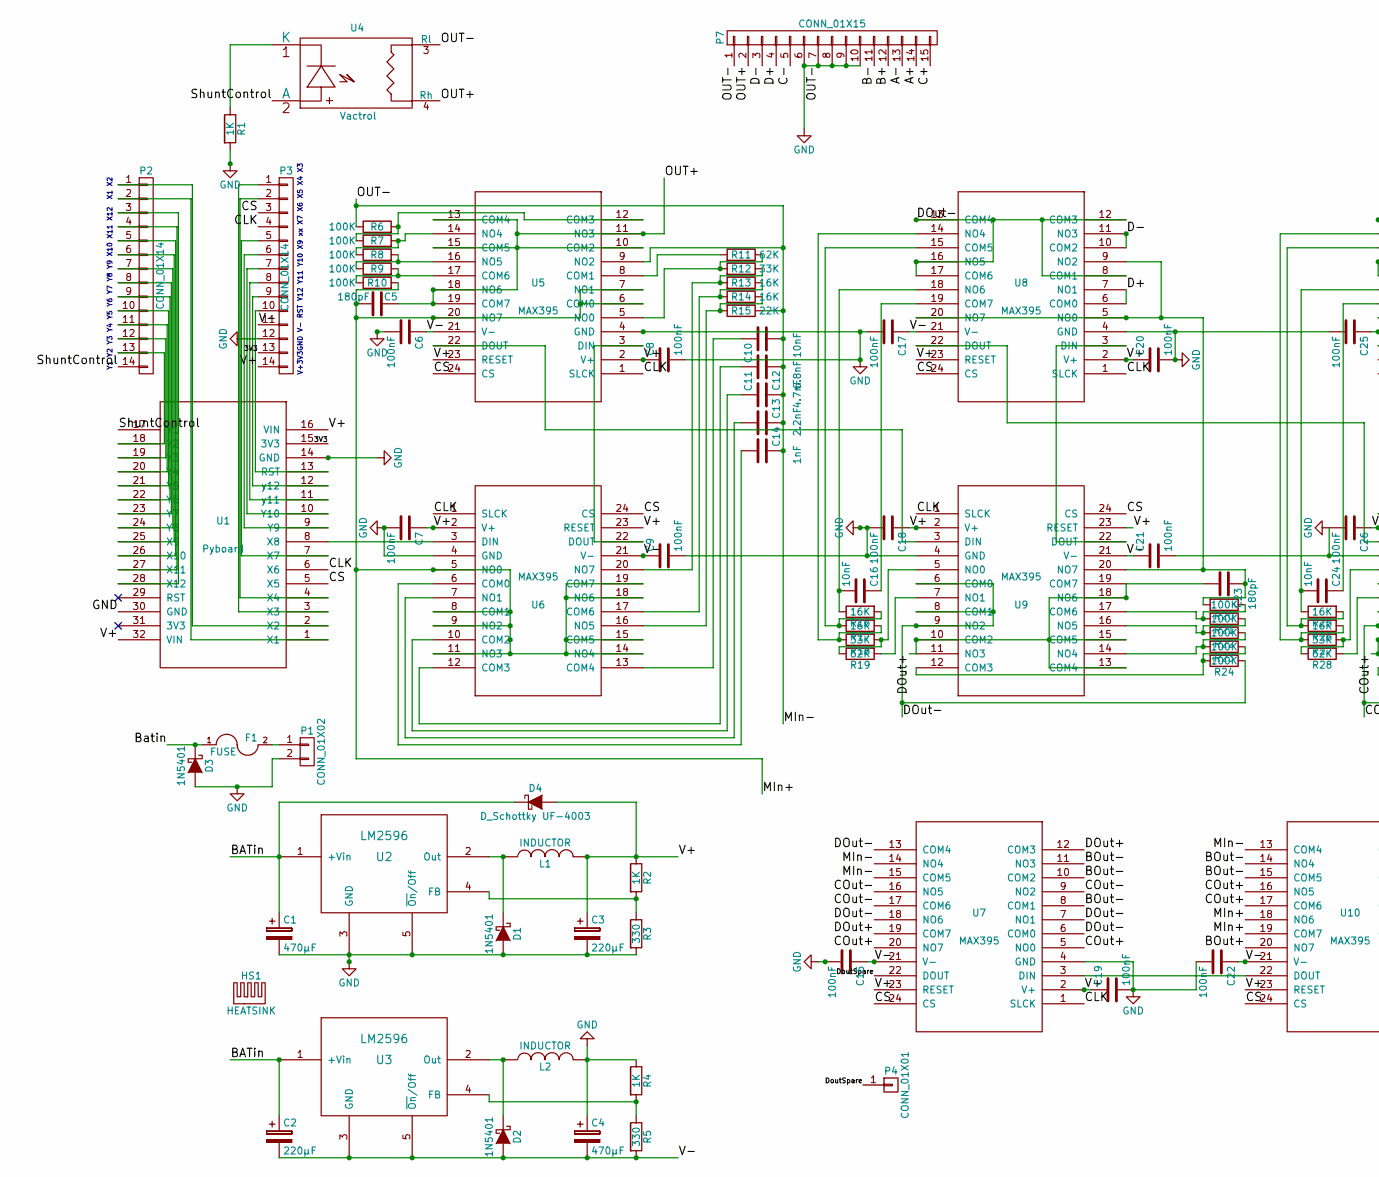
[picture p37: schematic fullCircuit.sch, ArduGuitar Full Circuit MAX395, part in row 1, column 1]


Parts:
C1, C4: 470µF; C_Radial_D10_L16_P5
C2, C3: 220µF; C_Radial_D8_L11.5_P3.5
C5, C23, C31, C39, C46: 180pF; C_Disc_D3_P2.5
C6, C7, C8, C9, C15, C17, C18, C19, C20, C21, C22, C25, C26, C27, C28, C29, C30, C33, C34, C35, C36, C37, C38, C40, C42, C43, C44, C45: 100nF; C_Disc_D3_P2.5
C10, C16, C24, C32, C41: 10nF; C_Disc_D6_P5
C11: 6.8nF; C_Disc_D6_P5
C12: 4.7nF; C_Disc_D6_P5
C13: 2.2nF; C_Disc_D6_P5
C14: 1nF; C_Disc_D6_P5
D1, D2, D3: 1N5401; Diode_DO-201AD_Horizontal_RM15
D4: D_Schottky UF-4003; Diode_DO-41_SOD81_Horizontal_RM10
F1: FUSE; Fuse_TE5_Littlefuse-395Series
HS1: HEATSINK; Heatsink_TO_220_38_20
L1, L2: INDUCTOR; 330L-Q9N_Inductor
P1: CONN_01X02; PINHEAD1-2
P2, P3: CONN_01X14; Pin_Header_Straight_1x14
P4: CONN_01X01; Pin_Header_Straight_1x01
P7: CONN_01X15; DB_15F-VGA_00_BOB
R1, R2, R4: 1K; Resistor_Horizontal_RM10mm
R3, R5: 330; Resistor_Horizontal_RM10mm
R6, R7, R8, R9, R10, R20, R21, R22, R23, R24, R29, R30, R31, R32, R33, R38, R39, R40, R41, R42, R47, R48, R49, R50, R51: 100K; Resistor_Horizontal_RM10mm
R11, R19, R28, R37, R46: 62K; Resistor_Horizontal_RM10mm
R12, R18, R27, R36, R45: 33K; Resistor_Horizontal_RM10mm
R13, R14, R16, R17, R25, R26, R34, R35, R43, R44: 16K; Resistor_Horizontal_RM10mm
R15: 22K; Resistor_Horizontal_RM10mm
U1: Pyboard; Pyboard16x2
U2, U3: LM2596; T05D
U4: Vactrol
U5, U6, U7, U8, U9, U10, U11, U12, U13, U14, U15, U16, U17, U18: MAX395; DIP-24__300_pads_70_10

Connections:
/3V3: P3.13, U1.15 (3V3)
/A+: P7.14, U17.6 (COM0), U17.7 (NO1)
/A-: P7.13, U17.10 (COM2), U17.11 (NO3)
/AOut+: C46.2, U16.6 (COM0), U16.7 (NO1), U16.10 (COM2), U16.11 (NO3), U16.16 (NO5), U16.18 (NO6), U16.19 (COM7), U18.10 (COM2), U18.11 (NO3), U18.13 (COM4), U18.15 (COM5), U18.18 (NO6), U18.19 (COM7)
/AOut-: R51.1, U13.6 (COM0), U13.7 (NO1), U13.10 (COM2), U13.11 (NO3), U13.16 (NO5), U13.18 (NO6), U13.19 (COM7), U17.8 (COM1), U17.12 (COM3), U17.13 (COM4), U17.16 (NO5), U17.17 (COM6), U18.6 (COM0), U18.8 (COM1), U18.9 (NO2)
/B+: P7.12, U14.6 (COM0), U14.7 (NO1)
/B-: P7.11, U14.10 (COM2), U14.11 (NO3)
/BATin: C1.1, C2.1, D3.1 (K), D4.1 (K), F1.1, U2.1 (+Vin), U3.1 (+Vin)
/BOut+: C39.2, U10.6 (COM0), U10.7 (NO1), U10.10 (COM2), U10.11 (NO3), U10.20 (NO7), U13.5 (NO0), U15.10 (COM2), U15.11 (NO3), U15.13 (COM4), U15.15 (COM5), U15.18 (NO6), U15.19 (COM7), U16.12 (COM3)
/BOut-: R42.1, U7.8 (COM1), U7.10 (COM2), U7.11 (NO3), U10.14 (NO4), U10.15 (COM5), U13.8 (COM1), U14.8 (COM1), U14.12 (COM3), U14.13 (COM4), U14.16 (NO5), U14.17 (COM6), U15.6 (COM0), U15.8 (COM1), U15.9 (NO2), U16.9 (NO2)
/C+: P7.15, U11.6 (COM0), U11.7 (NO1)
/C-: P7.5, U11.10 (COM2), U11.11 (NO3)
/CLK: P3.4, U1.6 (X6), U5.1 (SLCK), U6.1 (SLCK), U7.1 (SLCK), U8.1 (SLCK), U9.1 (SLCK), U10.1 (SLCK), U11.1 (SLCK), U12.1 (SLCK), U13.1 (SLCK), U14.1 (SLCK), U15.1 (SLCK), U16.1 (SLCK), U17.1 (SLCK), U18.1 (SLCK)
/COut+: C31.2, U7.5 (NO0), U7.20 (NO7), U10.12 (COM3), U10.16 (NO5), U10.17 (COM6), U12.10 (COM2), U12.11 (NO3), U12.13 (COM4), U12.15 (COM5), U12.18 (NO6), U12.19 (COM7), U13.9 (NO2), U16.8 (COM1)
/COut-: R33.1, U7.9 (NO2), U7.16 (NO5), U7.17 (COM6), U10.9 (NO2), U11.8 (COM1), U11.12 (COM3), U11.13 (COM4), U11.16 (NO5), U11.17 (COM6), U12.6 (COM0), U12.8 (COM1), U12.9 (NO2), U13.12 (COM3), U16.5 (NO0), U16.13 (COM4)
/CS: P3.3, U1.5 (X5), U5.24 (CS), U6.24 (CS), U7.24 (CS), U8.24 (CS), U9.24 (CS), U10.24 (CS), U11.24 (CS), U12.24 (CS), U13.24 (CS), U14.24 (CS), U15.24 (CS), U16.24 (CS), U17.24 (CS), U18.24 (CS)
/D+: P7.4, U8.6 (COM0), U8.7 (NO1)
/D-: P7.3, U8.10 (COM2), U8.11 (NO3)
/DOut+: C23.2, U7.12 (COM3), U7.19 (COM7), U9.10 (COM2), U9.11 (NO3), U9.13 (COM4), U9.15 (COM5), U9.18 (NO6), U9.19 (COM7), U10.8 (COM1), U13.14 (NO4), U13.15 (COM5), U16.14 (NO4), U16.15 (COM5)
/DOut-: R24.1, U7.6 (COM0), U7.7 (NO1), U7.13 (COM4), U7.18 (NO6), U8.8 (COM1), U8.12 (COM3), U8.13 (COM4), U8.16 (NO5), U8.17 (COM6), U9.6 (COM0), U9.8 (COM1), U9.9 (NO2), U10.5 (NO0), U13.17 (COM6), U16.17 (COM6)
/DoutSpare: P4.1, U7.22 (DOUT)
/MIn+: C5.1, R10.2, U5.6 (COM0), U5.7 (NO1), U5.20 (NO7), U6.5 (NO0), U6.8 (COM1), U6.9 (NO2), U6.11 (NO3), U6.14 (NO4), U6.15 (COM5), U6.18 (NO6), U6.19 (COM7), U10.18 (NO6), U10.19 (COM7), U13.13 (COM4), U16.20 (NO7)
/OUT+: C5.2, P7.2, U4.4 (Rh), U5.10 (COM2), U5.11 (NO3), U5.13 (COM4), U5.15 (COM5), U5.18 (NO6), U5.19 (COM7)
/ShuntControl: P2.14, U1.17 (Y1), U4.2 (A)
/V+: C3.1, C7.1, C8.1, C18.1, C19.1, C20.1, C26.1, C27.1, C29.1, C34.1, C35.1, C37.1, C40.1, C43.1, C44.1, D4.2 (A), L1.2, P3.14, R2.1, U1.16 (VIN), U1.32 (VIN), U5.2 (V+), U5.23 (RESET), U6.2 (V+), U6.23 (RESET), U7.2 (V+), U7.23 (RESET), U8.2 (V+), U8.23 (RESET), U9.2 (V+), U9.23 (RESET), U10.2 (V+), U10.23 (RESET), U11.2 (V+), U11.23 (RESET), U12.2 (V+), U12.23 (RESET), U13.2 (V+), U13.23 (RESET), U14.2 (V+), U14.23 (RESET), U15.2 (V+), U15.23 (RESET), U16.2 (V+), U16.23 (RESET), U17.2 (V+), U17.23 (RESET), U18.2 (V+), U18.23 (RESET)
/V-: C2.2, C4.2, C6.1, C9.1, C15.1, C17.1, C21.1, C22.1, C25.1, C28.1, C30.1, C33.1, C36.1, C38.1, C42.1, C45.1, D2.2 (A), P3.11, R5.2, U3.3 (GND), U3.5 (~On~/Off), U5.21 (V-), U6.21 (V-), U7.21 (V-), U8.21 (V-), U9.21 (V-), U10.21 (V-), U11.21 (V-), U12.21 (V-), U13.21 (V-), U14.21 (V-), U15.21 (V-), U16.21 (V-), U17.21 (V-), U18.21 (V-)
unnamed: C10.1, U6.13 (COM4)
unnamed: C11.1, U6.12 (COM3)
unnamed: C12.2, U6.10 (COM2)
unnamed: C13.2, U6.7 (NO1)
unnamed: C14.2, U6.6 (COM0)
unnamed: C16.1, U8.19 (COM7)
unnamed: C16.2, R16.1, U8.18 (NO6)
unnamed: C23.1, R20.2, U8.5 (NO0), U8.9 (NO2), U8.20 (NO7), U9.20 (NO7)
unnamed: C24.1, U11.19 (COM7)
unnamed: C24.2, R25.1, U11.18 (NO6)
unnamed: C31.1, R29.2, U11.5 (NO0), U11.9 (NO2), U11.20 (NO7), U12.20 (NO7)
unnamed: C32.1, U14.19 (COM7)
unnamed: C32.2, R34.1, U14.18 (NO6)
unnamed: C39.1, R38.2, U14.5 (NO0), U14.9 (NO2), U14.20 (NO7), U15.20 (NO7)
unnamed: C41.1, U17.19 (COM7)
unnamed: C41.2, R43.1, U17.18 (NO6)
unnamed: C46.1, R47.2, U17.5 (NO0), U17.9 (NO2), U17.20 (NO7), U18.20 (NO7)
unnamed: D1.1 (K), L1.1, U2.2 (Out)
unnamed: D2.1 (K), L2.1, U3.2 (Out)
unnamed: F1.2, P1.1
unnamed: P2.1, U1.2 (X2)
unnamed: P2.2, U1.1 (X1)
unnamed: P2.3, U1.28 (X12)
unnamed: P2.4, U1.27 (X11)
unnamed: P2.5, U1.26 (X10)
unnamed: P2.6, U1.25 (X9)
unnamed: P2.7, U1.24 (Y8)
unnamed: P2.8, U1.23 (Y7)
unnamed: P2.9, U1.22 (Y6)
unnamed: P2.10, U1.21 (Y5)
unnamed: P2.11, U1.20 (Y4)
unnamed: P2.12, U1.19 (Y3)
unnamed: P2.13, U1.18 (Y2)
unnamed: P3.1, U1.3 (X3)
unnamed: P3.2, U1.4 (X4)
unnamed: P3.5, U1.7 (X7)
unnamed: P3.7, U1.10 (Y10)
unnamed: P3.8, U1.11 (y11)
unnamed: P3.9, U1.12 (y12)
unnamed: P3.10, U1.13 (RST)
unnamed: R1.1, U4.1 (K)
unnamed: R2.2, R3.1, U2.4 (FB)
unnamed: R4.2, R5.1, U3.4 (FB)
unnamed: R6.2, R7.1, U5.12 (COM3)
unnamed: R7.2, R8.1, U5.14 (NO4)
unnamed: R8.2, R9.1, U5.16 (NO5)
unnamed: R9.2, R10.1, U5.17 (COM6)
unnamed: R11.1, R12.2, U5.5 (NO0)
unnamed: R11.2, U5.8 (COM1)
unnamed: R12.1, R13.2, U6.20 (NO7)
unnamed: R13.1, R14.2, U6.17 (COM6)
unnamed: R14.1, R15.2, U6.16 (NO5)
unnamed: R16.2, R17.1, U8.15 (COM5)
unnamed: R17.2, R18.1, U8.14 (NO4)
unnamed: R18.2, R19.1, U9.5 (NO0)
unnamed: R19.2, U9.7 (NO1)
unnamed: R20.1, R21.2, U9.17 (COM6)
unnamed: R21.1, R22.2, U9.16 (NO5)
unnamed: R22.1, R23.2, U9.14 (NO4)
unnamed: R23.1, R24.2, U9.12 (COM3)
unnamed: R25.2, R26.1, U11.15 (COM5)
unnamed: R26.2, R27.1, U11.14 (NO4)
unnamed: R27.2, R28.1, U12.5 (NO0)
unnamed: R28.2, U12.7 (NO1)
unnamed: R29.1, R30.2, U12.17 (COM6)
unnamed: R30.1, R31.2, U12.16 (NO5)
unnamed: R31.1, R32.2, U12.14 (NO4)
unnamed: R32.1, R33.2, U12.12 (COM3)
unnamed: R34.2, R35.1, U14.15 (COM5)
unnamed: R35.2, R36.1, U14.14 (NO4)
unnamed: R36.2, R37.1, U15.5 (NO0)
unnamed: R37.2, U15.7 (NO1)
unnamed: R38.1, R39.2, U15.17 (COM6)
unnamed: R39.1, R40.2, U15.16 (NO5)
unnamed: R40.1, R41.2, U15.14 (NO4)
unnamed: R41.1, R42.2, U15.12 (COM3)
unnamed: R43.2, R44.1, U17.15 (COM5)
unnamed: R44.2, R45.1, U17.14 (NO4)
unnamed: R45.2, R46.1, U18.5 (NO0)
unnamed: R46.2, U18.7 (NO1)
unnamed: R47.1, R48.2, U18.17 (COM6)
unnamed: R48.1, R49.2, U18.16 (NO5)
unnamed: R49.1, R50.2, U18.14 (NO4)
unnamed: R50.1, R51.2, U18.12 (COM3)
unnamed: U1.8 (X8), U6.3 (DIN)
unnamed: U5.3 (DIN), U6.22 (DOUT)
unnamed: U5.22 (DOUT), U9.3 (DIN)
unnamed: U8.3 (DIN), U9.22 (DOUT)
unnamed: U10.3 (DIN), U13.22 (DOUT)
unnamed: U7.3 (DIN), U10.22 (DOUT)
unnamed: U11.3 (DIN), U12.22 (DOUT)
unnamed: U11.22 (DOUT), U15.3 (DIN)
unnamed: U8.22 (DOUT), U12.3 (DIN)
unnamed: U13.3 (DIN), U16.22 (DOUT)
unnamed: U14.3 (DIN), U15.22 (DOUT)
unnamed: U14.22 (DOUT), U18.3 (DIN)
unnamed: U16.3 (DIN), U17.22 (DOUT)
unnamed: U17.3 (DIN), U18.22 (DOUT)

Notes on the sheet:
Y1 Y2 Y3 Y4 Y5 Y6 Y7 Y8 Y9 X10 X11 X12 X1 X2
V+3V3GND V- RST Y12 Y11 Y10 X9 xx X7 X6 X5 X4 X3

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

Board: 2 copper layers, 179.3 x 143.5 mm, 132 parts (0 on the bottom side), 126 nets.

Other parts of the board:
Hole1, Hole2, Hole3, Hole4: MountingHole_3mm

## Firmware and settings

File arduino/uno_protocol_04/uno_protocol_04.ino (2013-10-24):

/* uno_protocol 04:
 * uses ArduCom librairy, fixed to work for tests on a uno
 * 2013 09 12: uses progressive changing of PWM values to try to reduce "popping" sounds in amp
 * clears incoming buffer on error...
 * implements a serial protocol for receiving 5 bytes and translating them into
 * commands for pin writes
 * this version accepts strings of the form char[5]
 *   'ppvvv'  where p & v are on [0,9]
 *    and where int('pp') is on 0,13 or is 99 in case of heartbeat request
 *    and where int ('vvv') is on 0,255 or is 999 in case of heartbeat request
 *
 * This has been tested with pySerialRfcomm01.py and works perfectly!
 * updated 2013 03 28 for heartbeat
 */

// change USB_SERIAL to 0 to use the tx and rx pins
#define USB_SERIAL 1  
#if (USB_SERIAL)
#define SERIAL_CLASS Serial
#define SERIAL_CLASS_STRING "Serial"
#else
#define SERIAL_CLASS Serial1
#define SERIAL_CLASS_STRING "Serial1"
#endif

#include <outQueue.h>
#include <ArduCom.h>
//////////////////////////
// NOTE: this is the config for:
//    3 PWM output pins 9,10,11
//    12 digital output pins
//    Pins 0 & 1 are left out for use in Serial1 comms
//    also, we set phase-correct PWM on timers 0 & 1, for pwm pins 9,10, 3,11
const int incomingMsgSize = 5,
          pwmPins[] = {9,10,11},
          nbPWMPins = 3,
          allPins[] = {2,3,4,5,6,7,8,9,10,11,12,13},  // 0 & 1 are usef for RX and TX
          nbOutputPins = 12,
          currentIndex = 0,
          targetIndex = 1,
          firstPWMPin = 9;
/*
const String badPin = String("e00001"),
             badVal =  String("e00002");
*/          
int currentCharCount = 0,
    pwmValTargs[nbPWMPins][2] = {{0,0},{0,0},{0,0}}; // {{currentVal,TargetVal},...}
/*
char incomingBuffer[5] = "";
*/
ArduComSlave *com;

// end of Global Variables
////////////////////////////  

/*
void msg(const String s){
  // output the string to the serial device; NOTE: '\n' is NOT added, 
  // flush the output to be sure it is sent
  //SERIAL_CLASS.print(String("Arduino ") + String(SERIAL_CLASS_STRING));
  //SERIAL_CLASS.println(": " + s);
  Serial.print(s);
}

void msgb(const String s, char *buf, int len){
  // output the string to the serial device; NOTE: '\n' is NOT added, 
  // flush the output to be sure it is sent
  //SERIAL_CLASS.print(String("Arduino ") + String(SERIAL_CLASS_STRING));
  //SERIAL_CLASS.println(": " + s);
  char outC[len+1];
  for (int i=0 ; i< len ; i++){
    outC[i] = buf[i];
  }
  outC[len] = '\0';
  String outS = s + String(outC) + "\n";
  msg(outS);
}
*/
int dChar2D(const char c){
  // takes a charcter as input and return the corresponding digit as int
  // no error checking
  return int(map(c,'0','9',0,9));
}

boolean isIn(const int v, const int lis[], const int lisLen){
  // responds true id v is in lis up to lislen,
  // responds false otherwise.
  boolean res = false;
  for (int i=0;i<lisLen;i++){
    if (v==lis[i]){
      res=true;
      break;
    }
  }
  return res;
}

int io2Pin(const char* cp){
  // takes a pointer to a char[2], expecting only digits 
  // converts to a int
  // checks to be sure the resulting int is a member of allPins
  // returns a valid pin or -1 to indicate error
  int v0 = dChar2D(cp[0]),
      v1 = dChar2D(cp[1]);
  int res = int(v0*10+v1);
  if ((res != 99) && (!isIn(res,allPins,nbOutputPins))) { //(!isIn(res,allPins,nbOutputPins)) { 
    res = -1;
  }
  return(res);
}

int io2Val(const char* cv){
  // takes a pointer to a char[3], expecting only digits 
  // converts to a int
  // checks to be sure the resulting int is on [0,255]
  // returns a valid int or -1 to indicate error
  int v0 = dChar2D(cv[0]),
      v1 = dChar2D(cv[1]),
      v2 = dChar2D(cv[2]);
  int res = int(v0*100+v1*10+v2);
  if ((res != 999) && (res > 255)) { //(res>255) { 
    res = -1;
  }
  return(res);
}

boolean isPWM(const int p){
  // returns true if p is a member of pwmPins
  return isIn(p,pwmPins,nbPWMPins);
}


void  clearIncoming(){
  // somthing has gone wrong, clear the incoming serial stream.
  com->clearIncoming();
}

boolean executeIncomingString(char *buf, char*, int bufSize){
  // uses global variable incomingBuffer to extract
  // char[2] + char[5] and convert them to pin and value,
  // in case of error the type of error is determined
  // if no error, exectues the pin setting to value
  // calls 'msg' with a reply saying
  //  aPPVVV : analogWrite, PP = pin, VVV = value
  //  dPPVVV : digitalWrite, PP = pin, VVV = value
  //  eCCCCC : error, CCCCC = error code value
  /*
  const int pin = io2Pin(incomingBuffer),
            val = io2Val(incomingBuffer+2);
  */
  const int pin = io2Pin(buf+1),
            val = io2Val(buf+3);

  String //reply = "",
         analog = "a",
         digital = "d", 
         heartbeat = "x";
         
  if (pin<0) {
    buf[0] = 'e';
    //reply = badPin;
    clearIncoming();
  }
  else if (val < 0){
    buf[0] = 'e'; 
    //reply = badVal;
    clearIncoming();
  }    
  // add the heartbeat
  else if (pin == 99 && val == 999) {
    // don't change anything, just echo back that we are alive
    buf[0] = 'x'; 
    //reply = heartbeat;
  }
  else if (isPWM(pin)){
    //analogWrite(pin,val);
    setPWMTarget(pin,val);
    buf[0] = 'a'; 
    //reply = analog;
  }
  else if (val == 0) {
    digitalWrite(pin,LOW);
    buf[0] = 'd'; 
    //reply = digital;
  }
  else {
    digitalWrite(pin,HIGH);
    buf[0] = 'd'; 
    //reply = digital;
  }
  /*if (reply == digital || reply == analog || reply == heartbeat){ //(reply == digital || reply == analog){ 
      reply += pad(pin,2) + pad(val,3);
    }
  msg(reply);
  */
  //msgb("Replied: ", buf,6);
}
/*
String pad(int val,int places){
  // returns a String containgingc an int 'val' zero-padded to  length 'places'
  // no error checking
  String reply = String(val);
  const int missingZeros = places - reply.length();
  for (int i=0;i< missingZeros;i++){
    reply = String("0") + reply;
  }
  return (reply);
}
*/
void setPWMTarget(int pin,int val) {
    //      currentIndex = 0,
    //      targetIndex = 1,
    //      firstPWMPin = 9;
  pwmValTargs[pin-firstPWMPin][targetIndex] = val;
}

void pwmSetup(){
  // set up the hardware timers for phase-correct, maximum speed PWM
  // timer 1: pin 9 & 10
  TCCR1B = _BV(CS10); // change the PWM frequencey to 31.25kHz   - pins 9 & 10 
  // or is it _BV(CS00) ???
  TCCR1A = _BV(COM1A1) | _BV(COM1B1) | _BV(WGM10);  // phase-correct PWM on timer 1

  // timer 0 : pin 3 & 11
  TCCR0B = _BV(CS00); // change the PWM frequencey to 31.25 kHz  - pin 3 & 11
  TCCR0A = _BV(COM0A1) | _BV(COM0B1) | _BV(WGM00); // phase-correct pwm on timer 0  
}

void serialSetup(){
  com = new ArduComSlave(&SERIAL_CLASS,&executeIncomingString,ARDUCOM_MSGSIZE);
  com->doInit();
  /*
  // configure the Serial Object, then wait for the port to be ready
  //SERIAL_CLASS.begin(9600);
  SERIAL_CLASS.begin(115200);  // seems to add clicking?
  //SERIAL_CLASS.begin(1200);  // way too slow!
  
  while(!SERIAL_CLASS);
  //msg("initialized.");
  */
}

void protocolSetup(){
}

void pinSetup(){
  // set all the pins to output mode
  // set all digital pins to LOW
  // set all analogPins to 0
  for (int i=0; i< nbOutputPins;i++){
    pinMode(allPins[i],OUTPUT);
    digitalWrite(allPins[i],LOW);
  }
  for (int i=0; i< nbPWMPins;i++){
    analogWrite(pwmPins[i],0);
  }
  //msg(String("Pins initialized."));
}

void setup(){
  //pwmSetup();
  serialSetup();
  //protocolSetup();
  pinSetup();
}

void loop(){
  com->stepLoop();
  // step all the pwm values towards their targets
  for (int i=0; i< nbPWMPins;i++){
    if (pwmValTargs[i][currentIndex] == pwmValTargs[i][targetIndex]) {
      continue;
    }
    else {
      int step = (pwmValTargs[i][targetIndex] - pwmValTargs[i][currentIndex])/
                  abs(pwmValTargs[i][targetIndex] - pwmValTargs[i][currentIndex]);
      pwmValTargs[i][currentIndex] += step;
      analogWrite(pwmPins[i],pwmValTargs[i][currentIndex]);
      // this msg call is only for debugging;
      // it MUST BE REMOVED from running code when communicating with Android or Pyside GUIs
      //msg("Pin " + String(pwmPins[i]) + " stepped to " + String(pwmValTargs[i][currentIndex]) + ".\n");
    }
  }
}

/*  
void loop(){
  // read characters on the Serial object one by one,
  // if a full message has been read, process it and reset counter
  // otherwise continue reading
  //
  // If we have a full message and can process it
  if (currentCharCount == incomingMsgSize) {
    executeIncomingString();
    currentCharCount = 0;
  }
  // if there's something to read, add it to the incoming buffer and update the
  // charcter count
  if (SERIAL_CLASS.available() > 0) {
    // read one char and add it to the buffer
    incomingBuffer[currentCharCount++] = SERIAL_CLASS.read();
  }
  // step all the pwm values towards their targets
  for (int i=0; i< nbPWMPins;i++){
    if (pwmValTargs[i][currentIndex] == pwmValTargs[i][targetIndex]) {
      continue;
    }
    else {
      int step = (pwmValTargs[i][targetIndex] - pwmValTargs[i][currentIndex])/
                  abs(pwmValTargs[i][targetIndex] - pwmValTargs[i][currentIndex]);
      pwmValTargs[i][currentIndex] += step;
      analogWrite(pwmPins[i],pwmValTargs[i][currentIndex]);
      // this msg call is only for debugging;
      // it MUST BE REMOVED from running code when communicating with Android or Pyside GUIs
      //msg("Pin " + String(pwmPins[i]) + " stepped to " + String(pwmValTargs[i][currentIndex]) + ".\n");
    }
  }
}
*/

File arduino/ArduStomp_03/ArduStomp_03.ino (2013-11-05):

/* ArduStomp_02
 * code to command the ARduGuitar from an arduino based stomp box.
 * integrating coms and BT
 */

//#include <Arduino.h>
#include <outQueue.h>
#include <ArduCom.h>
#include <RN42autoConnect.h>

#include "confClass.h" 
#include "actuatorClass.h"

// minimum millis between button presses
#define MIN_TIME_BETWEEN_BUTTON_PRESSES 100

#define VUP_PIN 2
#define VDW_PIN 3
#define TUP_PIN 4
#define TDW_PIN 5
#define N_PIN   6
#define M_PIN   7
#define B_PN    8
#define P_PIN   9
#define A_PIN   10


ArduComMaster *c;
/*
const int pins[]= {VUP_PIN,
                   VDW_PIN,
                   TUP_PIN,
                   TDW_PIN,
                   N_PIN,
                   M_PIN,
                   B_PN,
                   P_PIN,
                   A_PIN };
*/
const int nbButtons = 9;

confClass conf;

// for led shift register shifting
//Pin connected to latch pin (ST_CP) of 74HC595
const int latchPin = 13;
//Pin connected to clock pin (SH_CP) of 74HC595
const int clockPin = 12;
////Pin connected to Data in (DS) of 74HC595
const int dataPin = 11;

const int ledArraySize =24;
boolean leds[ledArraySize];

// these pairs say the LED starting index and how many there are in the button control group
const int volLedIndex[2] = {1,5},   
          neckLedIndex[2] = {6,1},
          middleLedIndex[2] = {7,1},
          toneLedIndex[2] = {9,5},   
          bridgeLedIndex[2] = {14,2},   
          presetLedIndex[2] = {17,4},   
          autoLedIndex[2] = {21,1},   
          powerLedIndex[2] = {22,1},   
          connectLedIndex[2] = {23,1};

const int *indexLis[] = {  volLedIndex,
                           neckLedIndex,
                           middleLedIndex,
                           toneLedIndex,
                           bridgeLedIndex,  
                           presetLedIndex,
                           autoLedIndex,
                           powerLedIndex,  
                           connectLedIndex};
  
#define VOL     0
#define NECK    1
#define MIDDLE  2
#define TONE    3
#define BRIDGE  4
#define PRESET  5
#define AUTO    6
#define POWER   7
#define CONNECT 8

/////////////////////////
#include <SD.h>

File myFile;

void SDtest(){
  //int i;
  //Serial.begin(9600);
  //Serial.println("\r\nHobbytronics Test Program for SD card...");  
  //Serial.println("Initializing SD card...");
  // On the Ethernet Shield, CS is pin 4. It's set as an output by default.
  // Note that even if it's not used as the CS pin, the hardware SS pin 
  // (10 on most Arduino boards, 53 on the Mega) must be left as an output 
  // or the SD library functions will not work. 
  pinMode(10, OUTPUT);
   
  if (!SD.begin(9)) {
    //Serial.println("initialization failed!");
    return;
  }
  //Serial.println("initialization done.");
  /*
  if (SD.exists("test.txt")) {
    SD.remove("test.txt");
  }
  
  myFile = SD.open("test.txt", FILE_WRITE);
  
  // if the file opened okay, write to it:
  if (myFile) {
    //Serial.println("Writing to test.txt...");
    //Serial.println("Hobbytronics Test");    
    for(int i=0;i<20;i++){
      myFile.println("Hobbytronics Test of file writing");    
    }  
    // close the file:
    myFile.close();
    //Serial.println("done.");
  } 
  else {
    // if the file didn't open, print an error:
    //Serial.println("error opening test.txt");
  }
  */
  // re-open the file for reading:
  //Serial.println("\n\rReading from test.txt...");  
  myFile = SD.open("test.txt");
  if (myFile) {
    
    // read from the file until there's nothing else in it:
    while (myFile.available()) {
    	//Serial.write(myFile.read());
   
    }
    // close the file:
    myFile.close();
  } 
  else {
    // if the file didn't open, print an error:
    //Serial.println("error opening test.txt");
  }
  //Serial.println("Test Complete.");  
}
////////////////////////////////

// return a point to the part of the array where the thing starts
boolean* getBools(int indicator){
  return &leds[indexLis[indicator][0]];
}


// This method sends bits to the shift registers:
void registerWrite() {
  // turn off the output so the leds don't light up
  // while you're shifting bits:
  digitalWrite(latchPin, LOW);

  byte outgoing[] = {0,0,0};
  for (int i =0;i<24;i++){
    if (leds[i]){
      outgoing[int(i/8)] |= 1 <<(7 - (i%8));
    }
  }

  //Serial.println("outgoing[0] = " + String(outgoing[0]));
  //Serial.println("outgoing[1] = " + String(outgoing[1]));  
  //Serial.println("outgoing[2] = " + String(outgoing[2]));  
  
  for (int i = 2;i>-1 ;i--){
    shiftOut(dataPin, clockPin, LSBFIRST, outgoing[i]);
  }
  // turn on the output so the LEDs can light up:
  digitalWrite(latchPin, HIGH);
}

////////////////////////////////////////////////////////////
////////////////////// for debugging  //////////////////////
////////////////////////////////////////////////////////////
/// these show*Led* fucntions need to be updated to get rid of msg part
/////
/*
const String buttonNames[] = {"Vol Up",
                              "Vol Down",
                              "Tone Up",
                              "Tone Down",
                              "Neck",
                              "Middle",
                              "Bridge",
                              "Preset",
                              "Auto"};
                             
void showVolLeds(){
  String   s = "Vol: ";
  for (int i=0;i<indexLis[VOL][1];i++){
    s += String(getBools(VOL)[i])  +" ";
  }
  msg(s);
  showLeds();
}

void showNeckLed(){
  msg("Neck: " +String(*getBools(NECK)));
  showLeds();
}
void showMiddleLed(){
  msg("Middle: " +String(*getBools(MIDDLE)));
  showLeds();
}
void showBridgeLeds(){
  String s = "Bridge: ";
  for (int i=0;i<indexLis[BRIDGE][1];i++){
    s += String(getBools(BRIDGE)[i]) +" ";
  }
  msg(s);
  showLeds();
}  
void showToneLeds(){
  String  s = "Tone: ";
  for (int i=0;i<indexLis[TONE][1];i++){
    s += String(getBools(TONE)[i]) +" ";
  }
  msg(s);
  showLeds();
}
void showPresetLeds(){
String  s = "Preset: ";
  for (int i=0;i<indexLis[PRESET][1];i++){
    s += String(getBools(PRESET)[i]) +" ";
  }
  msg(s);
  showLeds();
}
void showAutoLed(){
  msg("Auto: " +String(*getBools(AUTO)));
  showLeds();
}

void showPowConLeds(){
  msg("Power: " +String(*getBools(POWER)));
  msg("Connected: " +String(*getBools(CONNECT)));
  showLeds();
}  
void showLeds(){
  registerWrite();
  msg("LEDs updated!");
}
*/
////////////////////////////////////////////////////////////
////////////////////// end debugging  //////////////////////
////////////////////////////////////////////////////////////

void vtLeds(boolean arr[],int nb,int level){
  // set leds for vol, tone, presets
  for(int i=0;i<nb;i++){
    if (i< level){
      arr[i] = true;
    }
    else {
      arr[i] =  false;
    }
  }
}

long lastActionTime = 0;
const long minActionDelay = MIN_TIME_BETWEEN_BUTTON_PRESSES;
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

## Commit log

2013-04-16 added threading to python version, added lots of Processing tests
    [ArduGuitarPresets_wrote.csv, DataWrite-data.tsv, data.csv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]
2013-04-18 new version of AndroidPickupsBT and new micro_protocol to hand errors
    [micro_protocol_02.ino]
2013-04-21 preset functions in Processing version ArduGuitarAndroid
    [DataWrite-data.tsv]
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2013-06-15 fixed bt request on Android Demo App
    [Bluetooth.pde]
2013-06-15 working on cycle load
    [data.tsv, def.csv, def.tsv]
2013-09-11 fully functional cyle package created in TimerThreadTest
    [presets.csv]
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2013-09-13 NoRN42 simulator corrected to minimalize data transmission
    [Bluetooth.pde, Conf.pde, Hal.pde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]
2013-09-18 fixed switching and display bugs
    [cycle.tsv]
2013-09-18 update to TimerThreadTest - now OK for Android
    [cycle.tsv]
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2013-09-25 cylcing version for NoBT ready
    [cycle.tsv, data-no-auto.tsv, tableRows.tsv]
2013-09-26 update BT for cycling and correct errors from past
    [Conf.pde, CycleClass.pde, Hal.pde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]
2013-09-26 fixed BT connect and first send problems
    [Bluetooth.pde, Conf.pde, Hal.pde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]
2013-09-26 fixed minor typos and formatting
    [Conf.pde, NoBTRN42ArduGuitar.pde]
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2013-11-01 minor changes to ArduStomp04 much more work needed to clear memory problems.
    [ArduStomp_04.ino, confClass.cpp]
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2013-11-06 New Led circuit with BIN display and SPI library
    [ArduStomp00.fzz, ArduStomp01.fzz]
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2013-11-10 major debug success - new circuit layout for bridge leds
    [ArduStomp01.fzz]
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2013-11-15 removed power and connect LEDs, now using 2 leds for each pup
    [ArduStomp00.skp, ArduStomp02.fzz]
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2013-11-18 PCB03 now contains all 3 views up to date and synched
    [ArduStomp02.fzz, ArduStomp02schematic.fzz, ArduStompPCB02.fzz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]
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2013-11-21 Switches labels corrected on Breadboard na Schematic Views - were already correct on PCB view
    [ArduStompPCB03.fzz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]
2013-11-21 removed extra connector on PCB folowing Jean_s suggestion
    [ArduStompPCB03.fzz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]
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2013-11-29 Working on the 2D model for laser cutting
    [LaserPrepTest00.skp, LaserPrepTest01.skp, LaserPrepTest02.skp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]
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2013-12-02 first draft of full laser cut layouts - still need to validate and kerf
    [Arcs08.skp, Arcs09.skp]
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2013-12-15 update to 2D model for better laser cutter
    [FullDesign06.dwg]
2013-12-15 finished base, back, front, sides and supports, still have to mirror top and make 10 arcs
    [Arcs20.skp, FullDesign06.dwg]
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2013-12-22 another version of the DraftSight model... when will it ever be finished..
    [BoxTest.dwg, BoxTest2.dwg, BoxTest2kerf05.dwg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]
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2013-12-22 2007 dwg files for 3mm and 6mm cuts are ready
    [FullDesign10_3mm_text_all_arcs_mirror_01.dwg, FullDesign10_3mm_text_all_arcs_mirror_02.dwg, FullDesign10_3mm_text_all_arcs_mirror_03.dwg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]
2013-12-23 partial update of model after first full scale laser cut in wood and cardboard - plenty remains to be fixed
    [FullDesign10_3mm_text_all_arcs_mirror_14_Laid_out.dwg, FullDesign10_3mm_text_all_arcs_mirror_15_Laid_out.dwg, FullDesign10_6mm_mirror_reverse11_laid_out.dwg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]
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2014-01-01 PCB soldered and ready to go into ArduStomp
    [Test_6mm_plexi_6_2_laid_out.dwg]
2014-01-02 update to write presets to SD card and removed all tracing
    [FullDesign10_3mm_test_Laid_out.dwg, Test_6mm_plexi_6_2_laid_out.dwg]
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2014-02-22 Ardu2Conf ok for now, SwitchManager fails tests...
    [Ardu2 full layout.fzz]
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2014-04-23 Input Stage PCB V4 looks like the winner
    [InputStage_Vol_Tone 03.fzz, InputStage_Vol_Tone 04.fzz]
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2014-10-10 Updates to POC-1, combinator still wrong, sigh...
    [POC Combinator Breadboard.fzz, POC Inverter Breadboard.fzz]
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2014-10-22 small correction in switch command logic spreadsheet
    [Switching Checklist.ods]
2014-10-22 cosmetic correction to switch breadboard
    [POC Switching Breadboard.fzz]
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2014-10-27 update to fix tone caps and resistors
    [POC Inverter Breadboard.fzz, POC Vol-Tone Breadboard.fzz]
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2014-11-19 upadte to switch array pcb after cb after paper prototype
    [SPDT Switch-Array-PCB.fzz]
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2014-12-06 new version of switch pcb as a result of failed etching
    [SPDT-JUMPER-Switch-Array-PCB-big-pads.fzz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]
2014-12-06 emergency correction of ground to be the v-
    [PSU +5v.fzz, PSU -5v.fzz, SPDT JUMPER Switch-Array-PCB.fzz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]
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2014-12-21 updates during soldering of switchboard - errors fond and corrected
    [SPDT-JUMPER-Switch-Array-PCB-big-pads.fzz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]
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2015-01-11 4316 array + PSU + Switchboard + LED simulation board all seem to work at this point
    [4316ArrayPCB.fzz, POC-2_4316_Switching Schematic.fzz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]
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2015-01-13 designed PCB for Inverter-Vol_Tone, corrected schematic as well
    [4316 Single Inverter and resistive tone control schematic .fzz, 4316-Inverter-Vol-Tone-PCB.fzz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]
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2015-03-03 corrected schematics for Tone control as per Lemme book
    [4316a Master Vol-resistive-tone control schematic .fzz, 4316a Single Inverter and resistive tone control schematic .fzz, POC-2a Schematic.fzz]
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2015-03-24 continued work on components and app - still some issues with conflicts of interest
    [app.py]
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2015-03-29 fixed issues with eval on pyboard - workaround is not nice but allows for loading of configs
    [app.py]
2015-04-03 update to 4316c Master VT schematic following discovery of error
    [4316c Master Vol-resistive-tone control schematic .fzz]
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2015-04-05 updates to hoefully correct schematics for tone
    [4316b Single Inverter and resistive tone control schematic .fzz, 4316c Master Vol-resistive-tone control schematic .fzz, 4316d Master Vol-resistive-tone contro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]
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2015-04-08 conformed schemtatics and dictMgr configs to experimental results
    [4316d Single Inverter and resistive tone control schematic .fzz, 4316f Master Vol-resistive-tone control schematic .fzz, Master-Vol-Tone-Scematic-c.fzz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]
2015-04-09 updates to schematics after discovery of errors during wiring
    [4316d Single Inverter and resistive tone control schematic .fzz]
2015-04-13 more work on the circuit and the 10PDT mount
    [10PDT Mount v2.fzz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]
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2015-05-02 vactrol control attempts at eliminating pop all failed
    [app.py]
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2015-05-08 update to the board connection overview still needs work
    [Overview MAX395.fzz]
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2015-05-19 still more work on pcb, really REALLY hard
    [Full-Circuit-PCB-Digital-a.fzz]
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2015-05-21 trying to make the pcb layouts, so so hard...
    [Full-Circuit-Scematic-Digital-b.fzz, Inverter-Vol-Tone-Scematic-Audio-e.fzz, Inverter-Vol-Tone-Scematic-Digital-e.fzz]
2015-05-22 update to MAX395 MVT Audio schematic version e
    [Master-Vol-Tone-Scematic-Audio-BAD-e.fzz, Master-Vol-Tone-Scematic-Audio-e.fzz, Master-Vol-Tone-Scematic-e-with-SPI.fzz]
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2015-05-28 ùore pcb kicad work, mostly failures
    [fullCircuit.dsn, fullCircuit.kicad_pcb, fullCircuit.sch]
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2015-05-31 updates after testing on breadboard - still need reverse polarity protection
    [ReverseCurrentProtection.fzz, Vactrol Direct Shunt a.fzz, fullCircuit.dsn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]
2015-05-31 reverse polarity added, Cout+ net corrected
    [fullCircuit.kicad_pcb, fullCircuit.sch]
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2015-10-25 more attempts with the pyboard and ps2 now using interrupts but not working yet
    [pyb.py]
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2015-10-27 ps2 interrupt version ok, but still has timing issues... that's enough
    [pyb.py]
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2015-10-28 updated ps2 interrupt version with a timeout to avoid hanging
2015-11-04 updates to the pcb layout this corresponds to the working prototype PCB
    [fullCircuit.kicad_pcb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]
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2015-12-13 New test code for interrupt driven input on tactile switches and 5-position seletors
    [HW Debounce Button.kicad_pcb, HW Debounce Button.sch]
2015-12-17 trying to get HW debouncing to work with interrupts
    [HW Debounce Button.sch]
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2016-01-10 hw debouncing now works, circuit is updated, code remains the same.
    [HW Debounce Button.sch]
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2016-04-04 updated the HMI cut file for pb pcbs
    [#2PB with Headers-F.SilkS.dxf, #HMI_05_Guitar_Top_pb_mounting_holes.dxf, HMI_05_Guitar_Top_pb_mounting_holes.dxf]
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2016-05-22 fixed pb led not reading confdict issue
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2016-05-26 PyHMI is now complete. Next step: communicate with the pyboard
    [presets.csv]
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2016-05-29 corrected errors and finalized connection inversion parsing
    [presets.csv]
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2016-05-30 Fixed up PyComms to make it a useable example for others and for myself.
    [Asynch Q Mecahnics.dxf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]
2016-05-30 First integrated version of emulator with comms to the pyboard!
    [presets.csv]
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2016-06-01 new pcb, fixed the emulator code some
    [presets.csv]
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2016-06-06 beginning of the HMI integration with the pyboard code
    [Asynch Q Mecahnics.dxf, presets.csv]
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2016-06-08 implmented tracking style split pots, reverted pyboard firmware
    [presets.csv]
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2016-06-10 first integration of emulator, pyboard, circuits, guitar testbed!
    [presets.csv]
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2016-06-14 added my own version of a csv.py, seems ok, needs more tests...
    [presets.csv, ps.csv]
2016-06-15 more porting... recursion & memory problems...
    [app.py, pyb.py]
2016-08-13 some small fixes as the bytec-ompile version progresses.
    [presets.csv]
2016-08-25 fixed defect in the csv parsing, more checking still needed for default preset creation
    [presets-compare-source-vs-read-values.ods]
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2016-08-26 ported hradware.TrackBall, updated q to increase the qLen and try to avoid overload due to high trackabll spinning
    [app.py]
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2016-08-30 hardware all ported, no problems with reading and writing presets, sigh...
    [app.py]
2016-08-31 found dictionary bug, wrote workaround, and we now have a FULLY FUNCTIONAL SYSTEM
    [ps.csv, test1.csv]
2016-09-01 worked on demonstrating the frozen string issue
    [presets.csv, presets0.csv, test1.csv]
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2016-10-07 updates to fix what's broken, new MicroValuator class in test
    [app.py]
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2016-10-28 updated to HMI PCB after second SENSEI review
    [HMI-PCB-B.Cu.gbr, HMI-PCB-Edge.Cuts.gbr, HMI-PCB-F.Cu.gbr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]
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2016-12-24 seems like a working version with full PCB integraton
    [presets.csv, presets0.csv, presets0ld.csv]
2016-12-29 debugging the q problem
    [app.py]
2016-12-30 correcting sw defects - still 1 to go
    [app.py]
2016-12-31 fixed preset loading and created on LCD messaging - tested ok
    [defaultPresets.csv]
2017-01-02 fixed more conf defects and improved handling of loading and editing presets in view of fixing HW issue based on solid SW foundation
    [PickupWiring.kicad_pcb, PickupWiring.sch, WorkingPresetsSavedByPyboard.csv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]
2017-01-05 added schematics for std and reverse pot volume wiring
    [PickupWiring.sch]
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2017-01-08 fixed upper no parenthesis call in sParse
    [app.py]
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2017-02-13 added sd card files and no_debug version still to be tested
    [10PDT Soldering.dxf, WorkingPresetsSavedByPyboard.csv, defaultPresets.csv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]
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2017-06-09 more work on 3D printed parts for HMI
    [LaserCutTempBlocks2000.dxf, LaserCutTempBlocksR12.dxf]
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2018-02-12 AD75091 arduino code - failure
    [spiMgr.cpp, spiMgr.py]
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2018-05-16 updated ad75019 test for spi, corrected matrix index error
    [Gui.pde, spiMgr.cpp]
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

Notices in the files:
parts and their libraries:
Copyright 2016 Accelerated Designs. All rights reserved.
